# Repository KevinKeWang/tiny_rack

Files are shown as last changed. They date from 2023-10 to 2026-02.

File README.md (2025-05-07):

# tiny_rack
This is a V2 version of tiny_rack. With the release of the BambuLab H2D it's easy to print larger models. So I updated the eurorack case model for the 6U52HP, and the power board circuit for a more convenient and easy to use design. This version is closer to the aluminum eurorack case I sell. they are exactly the same in power and functionality. Now you can print your own 6U52hp eurorack case in any color you like!

tiny_rack_v2_1
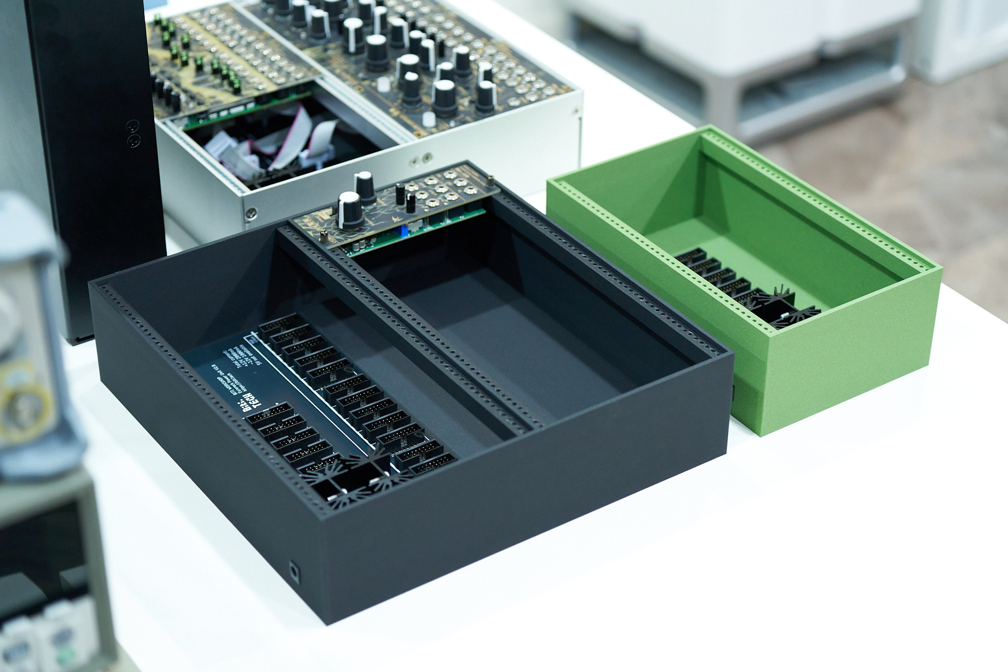
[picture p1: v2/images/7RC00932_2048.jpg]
tiny_rack_v2_2

**(tiny_rack v2)**

The first version is smaller and fits most 3D printers. If your printer cannot build such a large part, please browse the V1 version here: https://github.com/KevinKeWang/tiny_rack/tree/V1

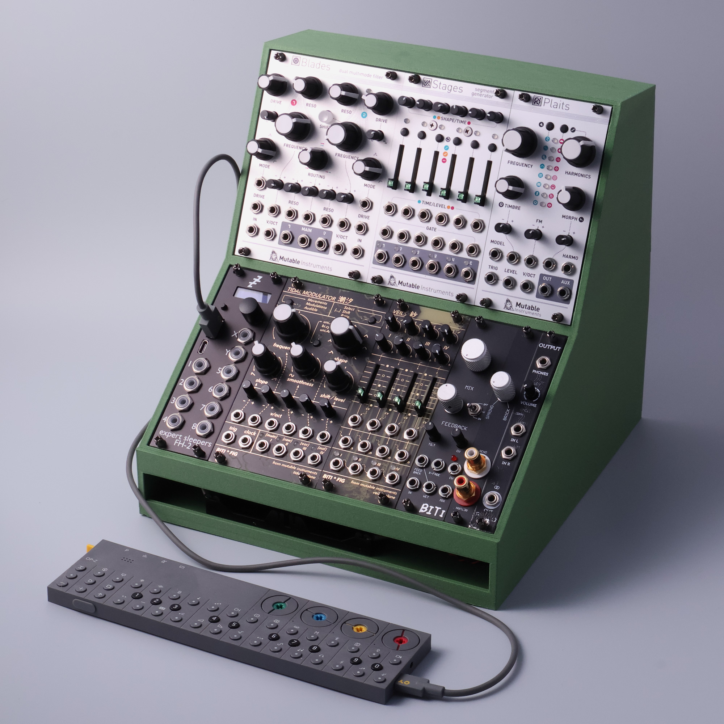
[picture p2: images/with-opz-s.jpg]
tiny_rack

**(tiny_rack v1)**

## Main features:

* One-piece 3D printed, no splicing, no metal rails required.
* Maximum current: +12V 2000mA, -12V 1000mA, +5V not available.
* Full load tested.
* The +12V and -12V output ripple is less than 100mV under all load conditions.
* Fully test powered by ZITAY D-Tap to DC(5.5 * 2.1 mm) Cable

## Portable scene using V-mount battery power supply
**Please note that the dtap output voltage should not be lower than 14.2V**
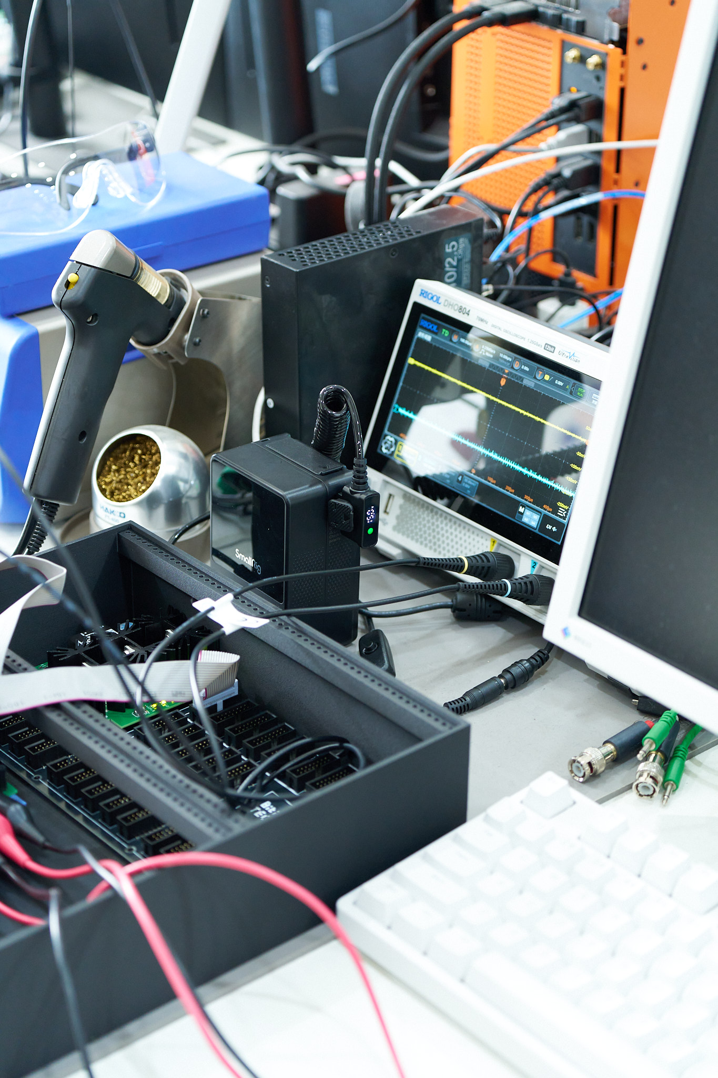
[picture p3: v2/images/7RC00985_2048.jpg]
portable_1
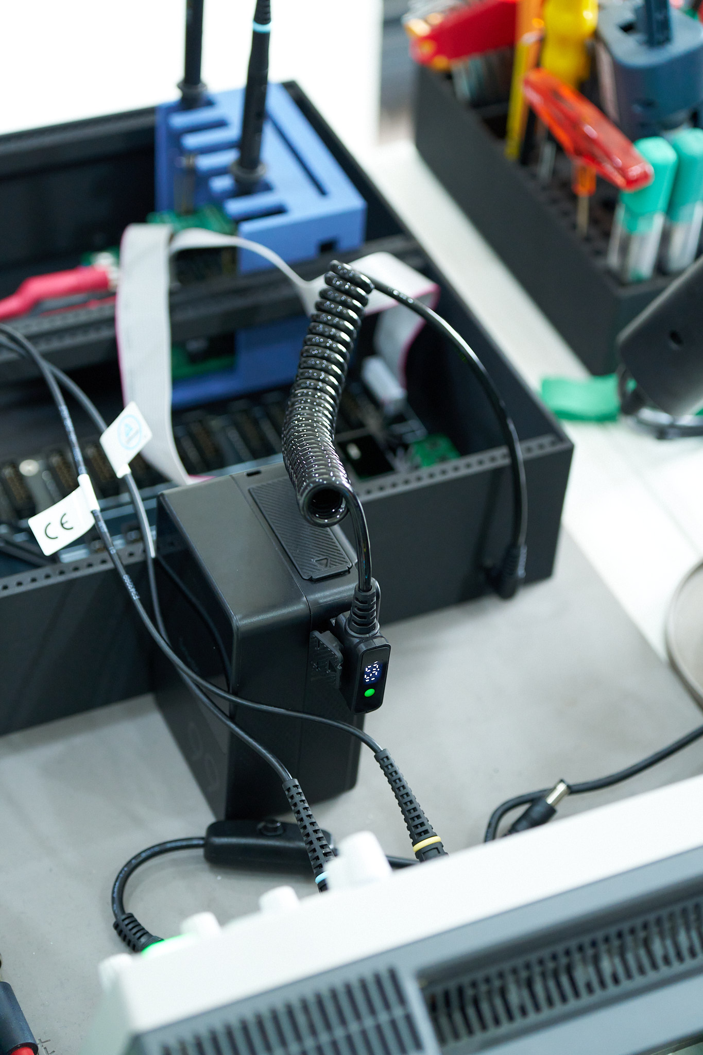
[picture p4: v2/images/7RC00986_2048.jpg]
portable_2
|  |  |
|---|---|

## Instructions
The main reason I started this project was the difficulty in finding a simple power bank solution when I was just starting out with DIY modulars. Most of the solutions required specialized rails. needed to control the precision otherwise the modulars would be difficult to install. there were many power board solutions but I couldn't be sure about the quality of their output. Some switching power supplies cause digital modulars to fail to boot.

This series contains the complete series of racks. and a power board with a decent quality of output. The racks is built entirely using 3D printing. one piece (including the rails) and simple to print. the screw holes are not threaded and need to be force screwed in using M3 screws to create the threads. this sacrifices the strength of the racks somewhat. but again makes the build very simple and ready to use straight after printing.

The power supply uses the original 7812/7912 LDO scheme. which is simple and reliable. and I've tested the ripple on the +/-12V rails to under 100mV under all load conditions. You can check the test report. it's not a perfect solution at the moment. but you can see exactly what kind of standards it can achieve.

**I no longer provide 5V in the power supply since most modulars that use 5V can be switched to convert 5V from 12V**

## 3D Print Instructions
* Be sure to place the model vertically, otherwise the dimensions will be off after printing, resulting in the modular not being installed.
* I have provided BambuStudio project files that can be used as a reference for the support structure. gcode files can be used directly for printing.
* Because different brands or different diameters of nozzles may produce different results when printing small circular holes. I made a screw hole diameter test model here. It is recommended to use this model to test before printing the modular case, and select the appropriate screw hole diameter to modify the plasticity source file. When I use the BambuLab H2D printer with a 0.4mm nozzle, a 2.5mm screw hole is the best size. If you use the same printer as me, you can directly use my gcode file for printing.

## Schematics and PCB

**Core PCB front side**

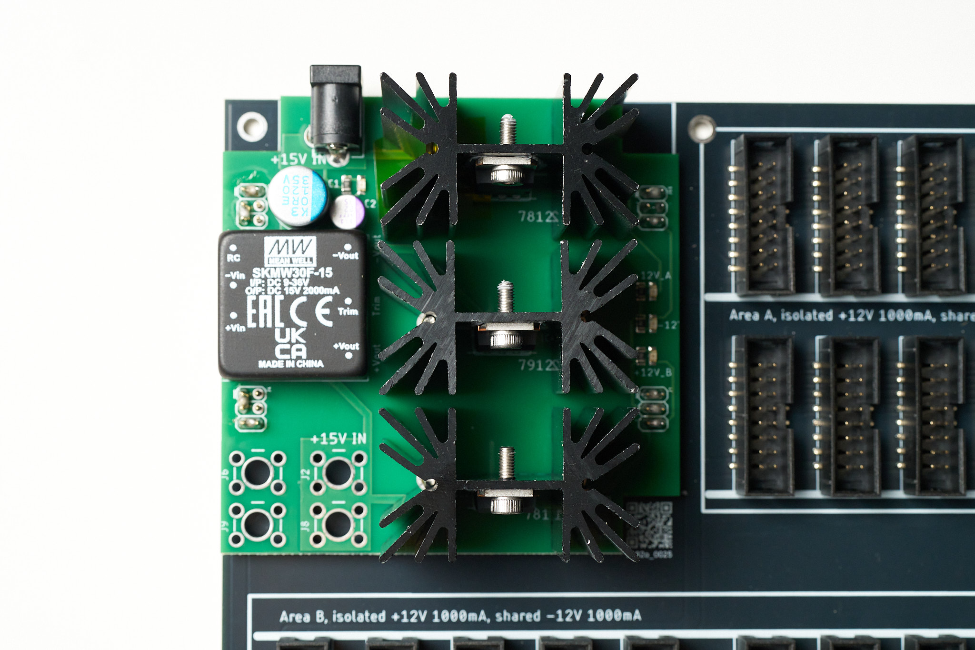
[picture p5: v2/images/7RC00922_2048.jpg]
pcb-front-side


**Core PCB back side**

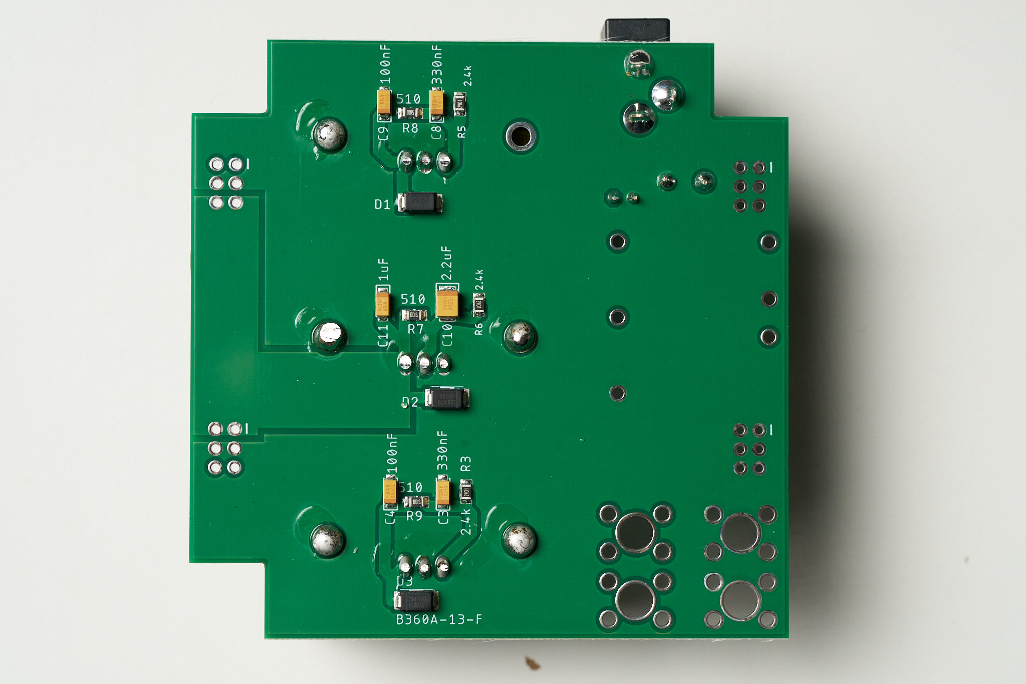
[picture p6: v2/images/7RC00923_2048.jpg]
pcb-back-side


**How to connect two PCBs**

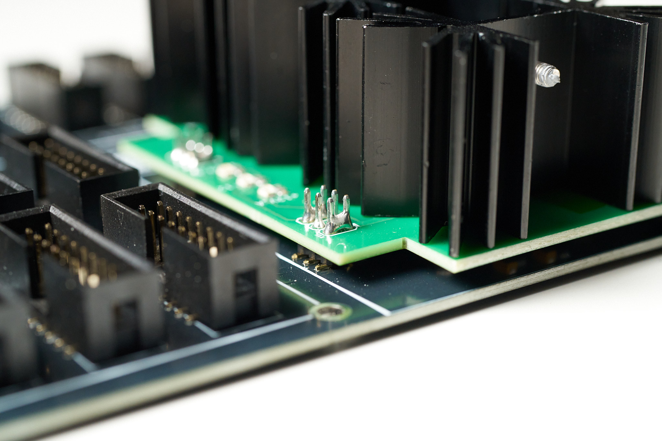
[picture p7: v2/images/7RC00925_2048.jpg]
pcb-connect


## Bill of materials (Core PCB)
| Designator | Qty | Value | Footprint | Description | Ref. Mouser | Ref. LCSC | References |
|---|-----|---|---|---|---|---|---|
| **SMT parts** | | | | | | | |
| LED1, LED2, LED3, LED4 | 4 | LED | 0805 | LED | 638-1215UYCS530A28 | C2987021  | EVERLIGHT 17-215/GHC-YP1Q2B16Y/3T |
| R1, R2, R3, R5, R6, R10, R4  | 7 | 2.4k | 0805 | Resistor | 667-ERJ-6ENF2401V | C17526 | UNI-ROYAL 0805W8F2401T5E |
| R7, R8, R9 | 3 | 510R | 0805 | Resistor (Optional) | 667-ERJ-6ENF5100V | C17734 | UNI-ROYAL 0805W8F5100T5E |
| C4, C9 | 2 | 100nF | CASE-A-3216 | tantalum | 581-TAJA104K035 | C7173 | Kyocera AVX TAJA104K035RNJ |
| C3, C8 | 2 | 330nF | CASE-A-3216 | tantalum | 581-TAJA334K035 | C8014 | Kyocera AVX TAJA334K035RNJ |
| C11 | 1 | 1uF | CASE-A-3216 | tantalum | 581-TAJA105K035R | C7176 | Kyocera AVX TAJA105K035RNJ |
| C10 | 1 | 2.2uF | CASE-B-3528 | tantalum | 581-TAJB225K035 | C19276 | Kyocera AVX TAJB225K035RNJ |
| D1, D2, D3 | 3 | DIODE | SMA(DO-214AC) | DIODE | 621-B360A-F | C94193 | DIODES B360A-13-F |
| **PTH parts** | | | | | | | |
| C2 | 1 | 22uF | D6.3xL7mm | Electrolytic | 647-UKL1V220KEDANA | C433313 | Nichicon USV1V220MFD |
| C1 | 1 | 120uF | D8xL7mm | Electrolytic | 667-50SEK120M | C3010233  | PANASONIC 50SEK120M |
| KK1, KK3, KK4 | 3 | Heat sink | | Heat sink | 532-529702B25G | C286227 | Heat sink |
| J1 | 1 | DC Power Connector | | 2.1 mm, 5.5 mm | 710-694106301002 | C136744 | Wurth Elektronik 694106301002 |
| J2, J6 | 2 | M3 screw terminal  | | terminal (Optional) | 534-7770 | C481448 | Keystone 7770 |
| **Adapter** | | | | | | | |
| 15V Adapter | 1 | 15V Adapter | | GST60A15-P1J | 709-GST60A15-P1J | - | MEANWELL 15V DC Adapter |

**It is recommended to use the adapter model I have tested.**

## Bill of materials (EXP PCB)
| Designator | Qty | Value | Footprint | Description | Ref. Mouser | Ref. LCSC | References |
|---|-----|---|---|---|---|---|---|
| **SMT parts** | | | | | | | |
| J1, J2, J6, J7, J8, J9, J11, J12, J13, J14, J15, J16, J17, J18, J19, J20, J21, J22, J23, J24, J25, J26, J27, J28, J29, J30, J31, J32, J33, J34 | 30 | 2x8 header | 2.54mm pitch  | 2x8 header | 710-61231620621 | C2685064 | 2x8 male header, 2.54mm pitch |
| J3, J4, J5, J10 | 4 | 2x3 header | 2.54mm pitch  | 2x3 header | 710-61300621121 | C358692 | 2x3 male header, 2.54mm pitch |

## Mechanical assembly

**There is no circuit on the back of the expansion board, so it can be directly attached to any surface with tape.**

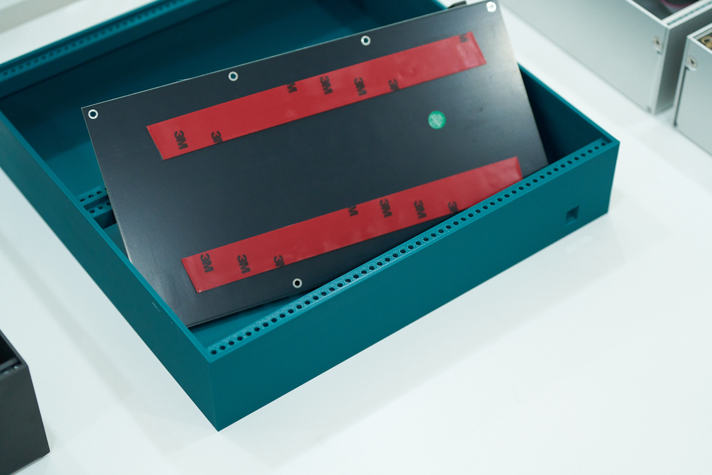
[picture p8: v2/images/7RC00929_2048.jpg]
mount_pic_1


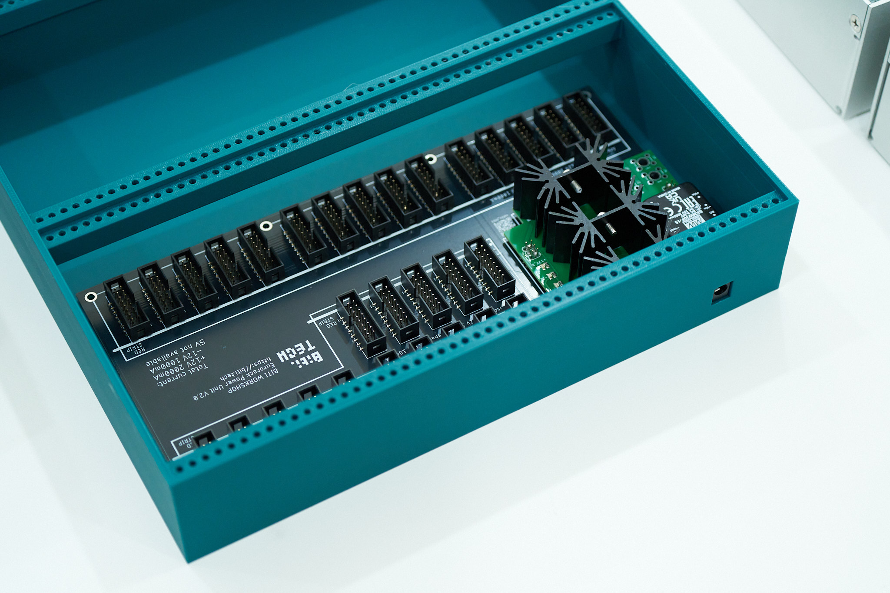
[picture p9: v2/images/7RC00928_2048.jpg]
mount_pic_2


## Software

3D Modeling Software: plasticity

https://www.plasticity.xyz/

PCB Software: eagle

https://www.autodesk.com/products/eagle/overview

## Test Report
Test equipment:
* Gwinstek GPP-3323 DC Power Supply (as an electronic load) **for +12V -12V**
* Itech IT8500G+ DC Electronic Load **for +5V**
* Rigol MSO5000 Oscilloscopes **for ripple measurement**
* Software for automated testing
Test methods:
Each channel is cycled from 0mA to maximum load, 50mA in one step, to test all combinations of loads and output a CSV file.

**There are some power supply solutions that can generate large ripple or even fail in specific load scenarios, such as when the gap between positive and negative rail loads is too large. That's why my tests cover all load scenarios.**

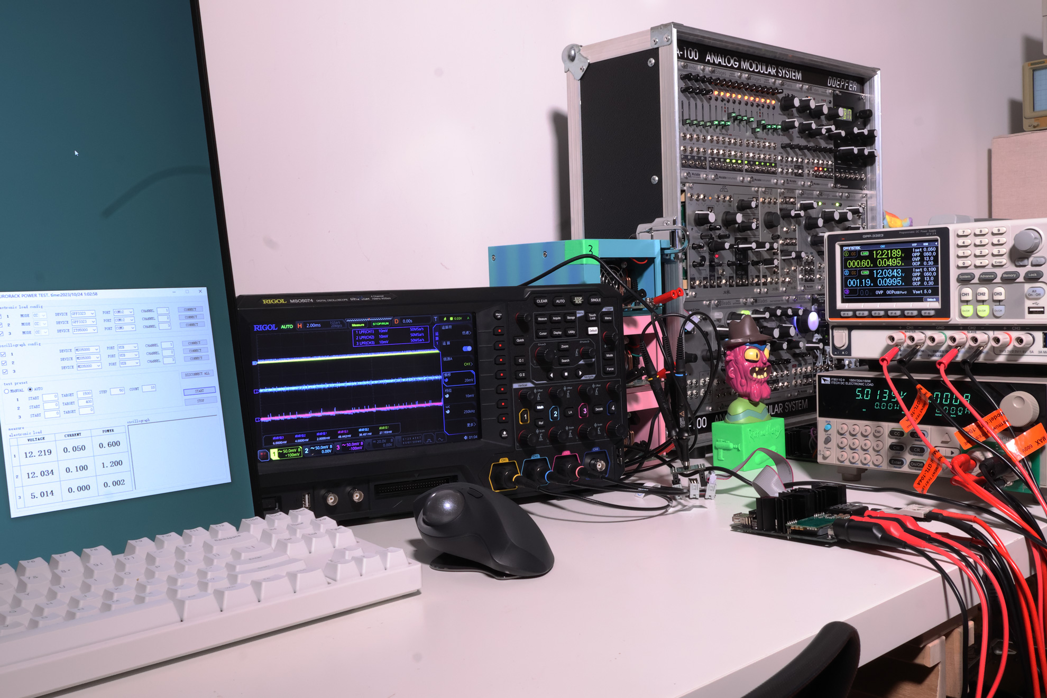
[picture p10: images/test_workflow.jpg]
test_workflow


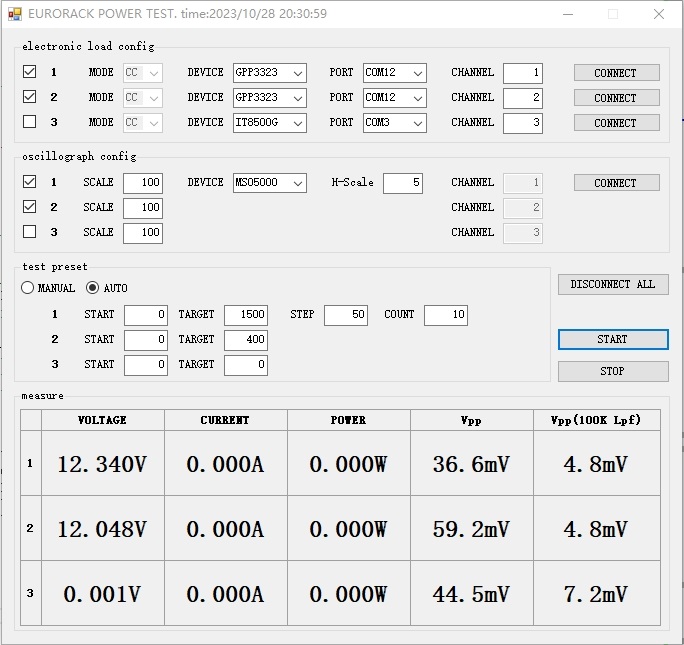
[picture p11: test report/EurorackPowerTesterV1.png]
test_software


## License
**The tiny_rack v2 project is made available under a CC-BY-NC-SA-3.0 license.**

If you want to make a few cases for your own use, go ahead and make them. If you're a synth studio and want to use them for product testing/demonstration etc, that's also welcome as long as it doesn't involve selling these case directly. **Please do not make and sell these case in bulk.**

## Links
Official website:  https://bitiworkshop.com/

Purchase here: https://store.bitiworkshop.com/

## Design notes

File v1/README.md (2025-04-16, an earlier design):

# tiny_rack
tiny_rack is a eurorack case (with power board) project for DIYer who just started DIY eurorack modular synthesizers.

tiny_rack

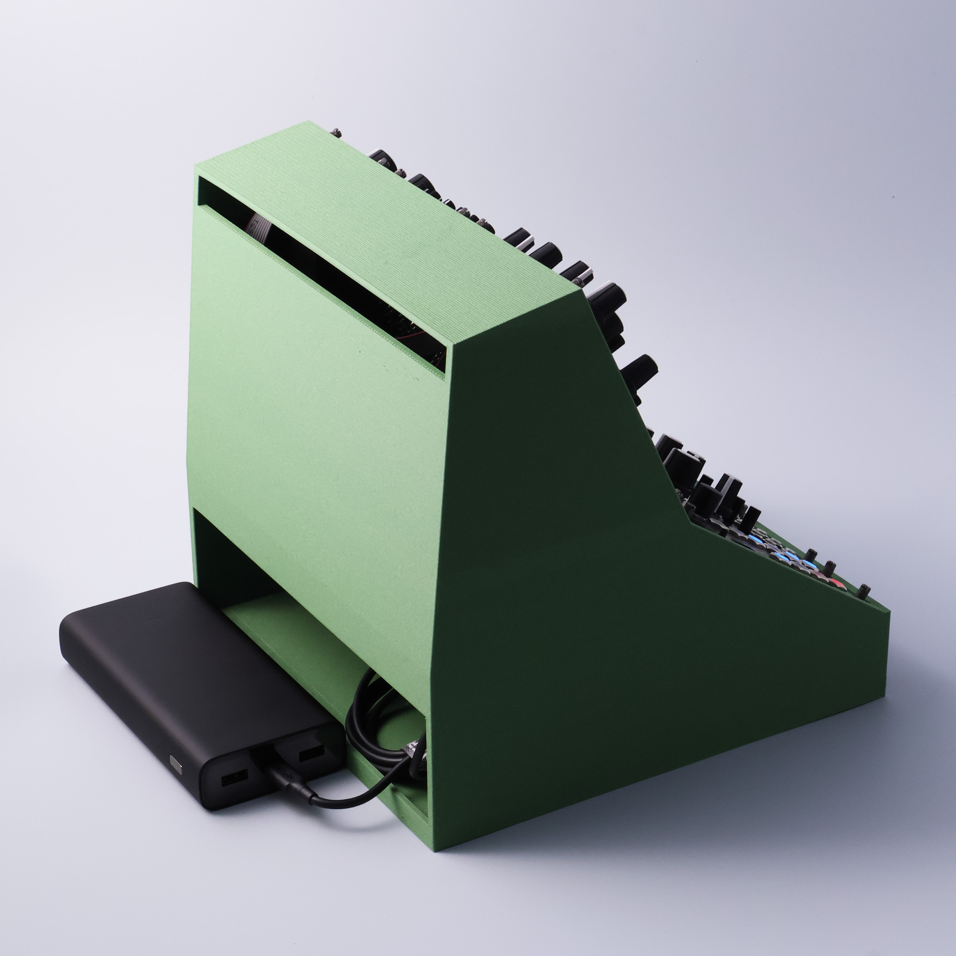
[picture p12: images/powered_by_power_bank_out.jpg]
powered_by_power_bank


## Main features:

* One-piece 3D printed, no splicing, no metal rails required.
* Maximum current: +12V 1500mA, -12V 1500mA, +5V 6500mA.
* Optional +3.3V 500mA for easy project prototyping.
* Full load tested.
* The +12V and -12V output ripple is less than 100mV under all load conditions.
* Exposed M3 screw terminals for direct connection to the test power supply. Clamps can be directly.
* Fully test powered by **[Mi 50w Power Bank 20000mAh](https://www.mi.com/global/product/mi-50w-power-bank-20000/)** (using a 15V USB decoy cable) 

**While this project puts the case and circuit together, they are both independently. This +/-12V 1500mA power supply is usually enough even in a 9U84hp case.**

## Type of rack
| Rack | Min depth | Max depth | Description |
|---|---|---|---|
| tiny-box-18hp | 28mm | 50mm | 18hp |
| tiny-box-26hp | 28mm | 50mm | 26hp |
| tiny-box-34hp | 28mm | 50mm | 34hp |
| tiny-box-42hp | 28mm | 50mm | 42hp |
| tiny-cube-26hp | 78mm | 100mm | 26hp, ultra deep |
| tiny-workbench-34hp | 50mm | 50mm | 34hp, for modular testing |
| tiny-rack-2x44hp | 55mm | 65mm | 2x44hp, more inner space for DIY |

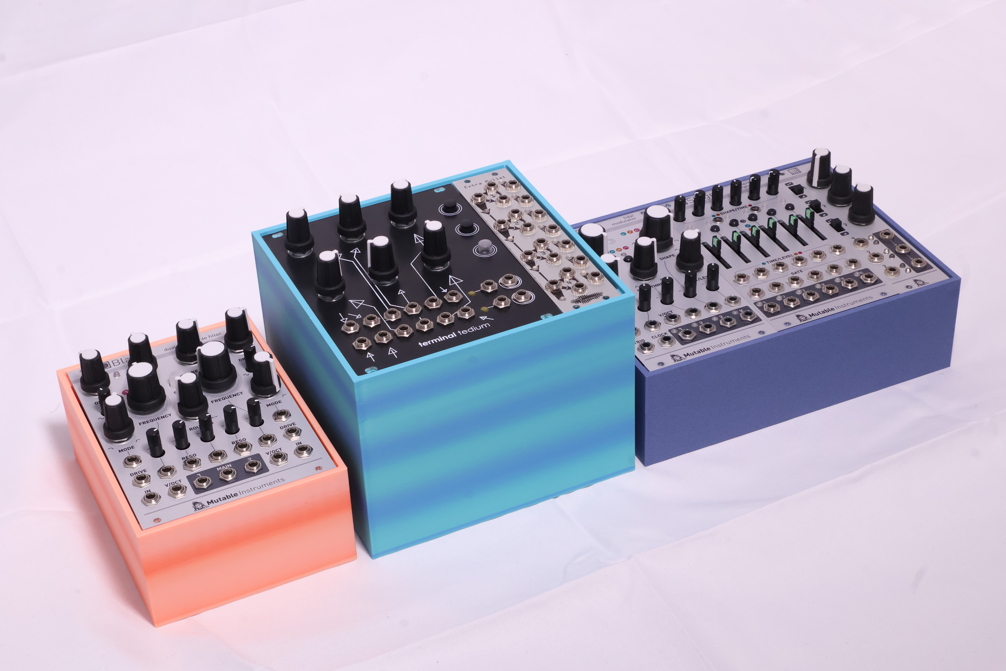
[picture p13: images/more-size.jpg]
more_size


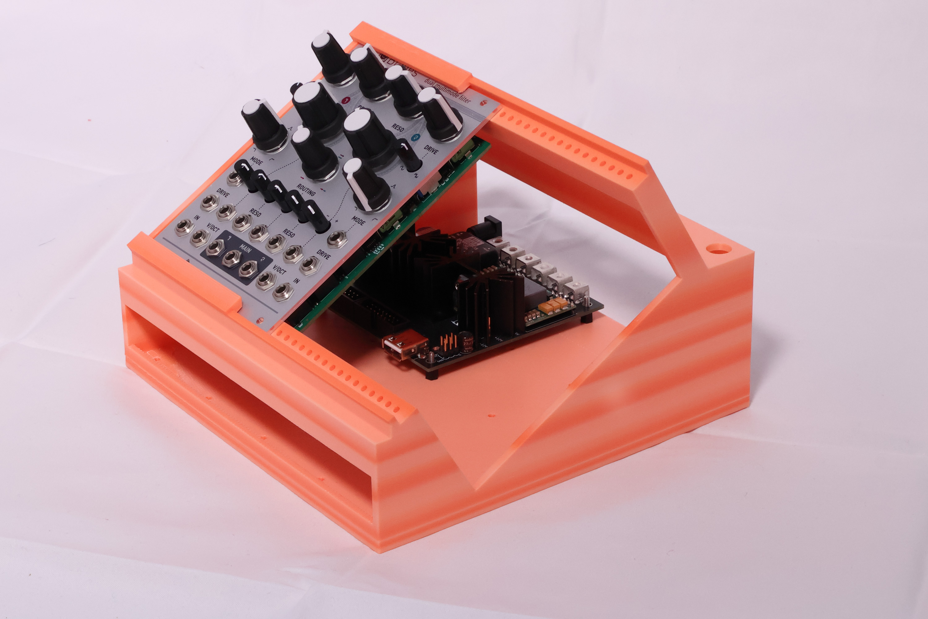
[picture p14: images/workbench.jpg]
workbench


## Instructions
The main reason I started this project was the difficulty in finding a simple power bank solution when I was just starting out with DIY modules. Most of the solutions required specialized rails. needed to control the precision otherwise the modules would be difficult to install. there were many power board solutions but I couldn't be sure about the quality of their output. Some switching power supplies cause digital modulars to fail to boot.

It took me some time to find the balance between ease of production and quality. This series contains the complete series of racks. and a power board with a decent quality of output. The racks is built entirely using 3D printing. one piece (including the rails) and simple to print. the screw holes are not threaded and need to be force screwed in using M3 screws to create the threads. this sacrifices the strength of the racks somewhat. but again makes the build very simple and ready to use straight after printing. All sizes of the racks are covered in 4CM x 4CM screw holes on the bottom and are compatible with all the PCBs in the project. so there is no need to change the power supply board if you need to change case sizes.

For the power supply. I tested several DC-DC isolation regulators and chose the model with the better output. the +12V rail provides 1500mA current output; the -12V rail can provide 1500mA or 400mA depending on the component selection. 5V rail is optional and can provide 3500mA or 6000A power output. which is perfectly adequate for the Raspberry Pi as well. Finally I have designed an optional 3.3V output pin. which is useful for DIY. if you have some project prototypes that need to use 3.3V this will give you some convenience.

The power supply uses the original 7812/7912 LDO scheme. which is simple and reliable. and I've tested the ripple on the +/-12V rails to under 100mV under all load conditions. You can check the test report. it's not a perfect solution at the moment. but you can see exactly what kind of standards it can achieve.
Regarding the heatsink. I designed two options. One is a standard component with soldering and the other is a customized heatsink with a hole spacing of 32mm x 32mm. with customized heat sink the height of power board can be much lower. 

**In the current scheme, the use of +5V is not recommended and will increase the output ripple on all channels.**

## 3D Print Instructions
* Be sure to place the model vertically, otherwise the dimensions will be off after printing, resulting in the modular not being installed.
* Do not add supports in the screw holes, extremely difficult to remove.
* I have provided BambuStudio project files in the "bumbu p1s" / "bumbu x1c" folder that can be used as a reference for the support structure. gcode files can be used directly for printing.
* It is also recommended to use 0.6mm nozzles. 0.4mm nozzles are often clogged.

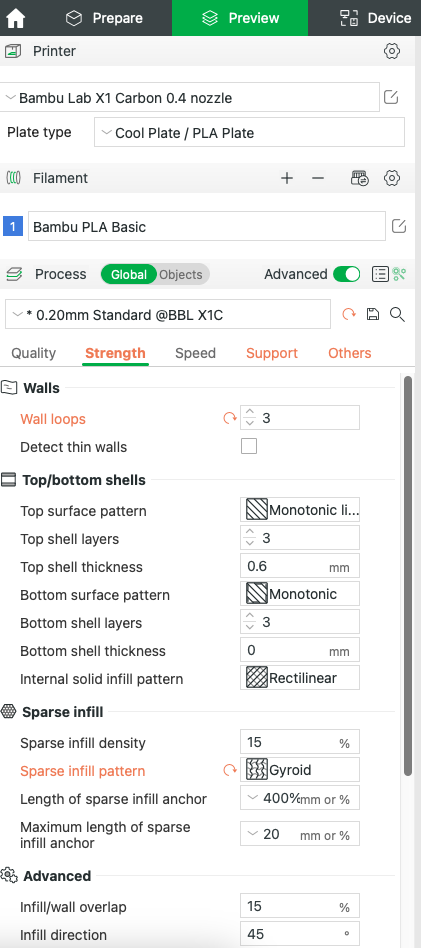
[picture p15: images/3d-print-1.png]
3D Printing Parameters 1

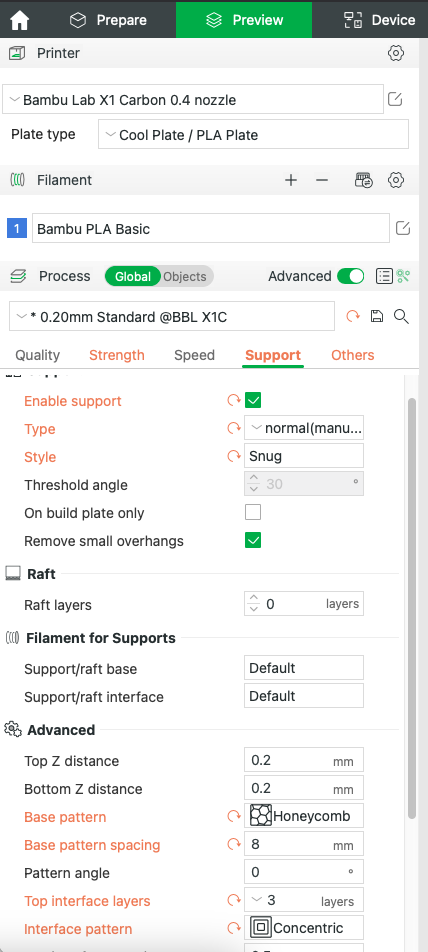
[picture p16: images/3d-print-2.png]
3D Printing Parameters 2

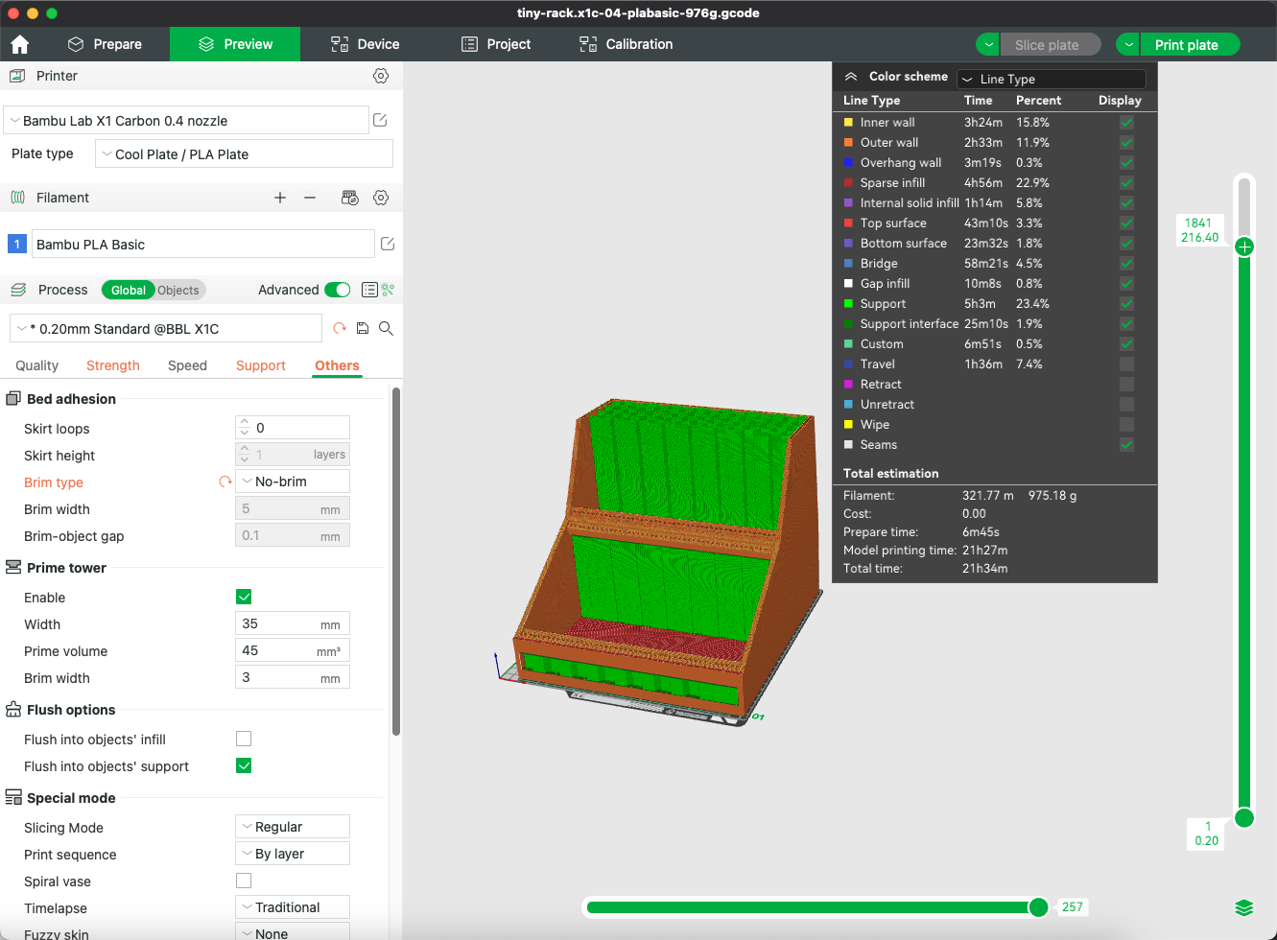
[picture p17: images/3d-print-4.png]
3D Printing Parameters 3


## Schematics and PCB
[All the PCB design files here](https://github.com/KevinKeWang/tiny_rack/tree/93aa4f3181c854528b71964095c1c5eb0407a9e2/power%20pcb "PCB Files")

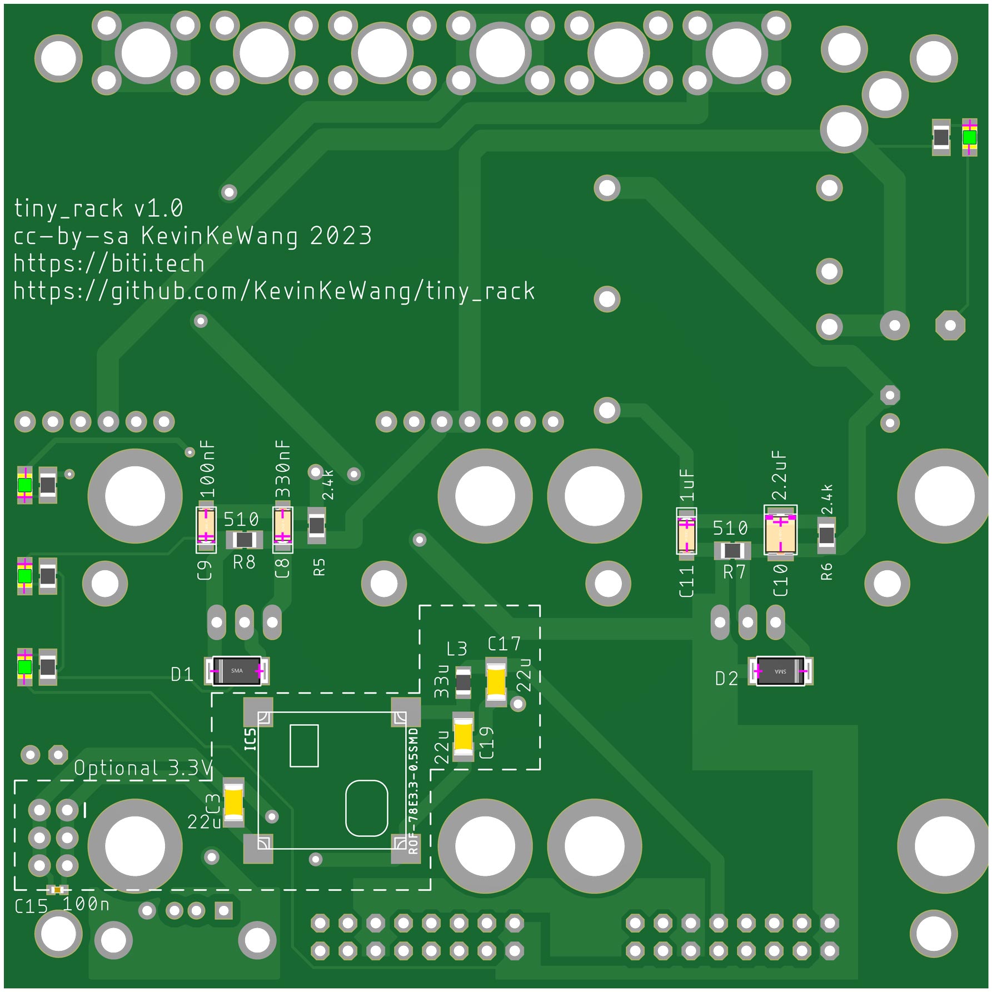
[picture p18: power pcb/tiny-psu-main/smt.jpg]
pcb


## Bill of materials
| Designator | Qty | Value | Footprint | Description | Ref. Mouser | Ref. LCSC | References |
|---|-----|---|---|---|---|---|---|
| **SMT parts** | | | | | | | |
| LED1, LED2, LED3, LED4 | 4 | LED | 0805 | LED | 638-1215UYCS530A28 | C2987021  | EVERLIGHT 17-215/GHC-YP1Q2B16Y/3T |
| R3 | 1 | 1.2k | 0805 | Resistor | 667-ERJ-6ENF1201V | C17379 | UNI-ROYAL 0805W8F1201T5E |
| R1, R2, R4 | 3 | 2.4k | 0805 | Resistor | 667-ERJ-6ENF2401V | C17526 | UNI-ROYAL 0805W8F2401T5E |
| R5, R6 | 2 | 2.4k | 0805 | Resistor (Optional) | 667-ERJ-6ENF2401V | C17526 | UNI-ROYAL 0805W8F2401T5E |
| R7, R8 | 2 | 510R | 0805 | Resistor (Optional) | 667-ERJ-6ENF5100V | C17734 | UNI-ROYAL 0805W8F5100T5E |
| C9 | 1 | 100nF | CASE-A-3216 | tantalum | 581-TAJA104K035 | C7173 | Kyocera AVX TAJA104K035RNJ |
| C8 | 1 | 330nF | CASE-A-3216 | tantalum | 581-TAJA334K035 | C8014 | Kyocera AVX TAJA334K035RNJ |
| C11 | 1 | 1uF | CASE-A-3216 | tantalum | 581-TAJA105K035R | C7176 | Kyocera AVX TAJA105K035RNJ |
| C10 | 1 | 2.2uF | CASE-B-3528 | tantalum | 581-TAJB225K035 | C19276 | Kyocera AVX TAJB225K035RNJ |
| D1, D2 | 2 | DIODE | SMA(DO-214AC) | DIODE | 621-B360A-F | C94193 | DIODES B360A-13-F |
| C15 | 1 | 100nF | 0402 | Ceramic (Optional for 3.3V) | 187-CL05B104KB54PNC | C307331 | SAMSUNG CL05B104KB54PNC |
| C3, C17, C19 | 3 | 22uF | 1206 | Ceramic (Optional for 3.3V) | 187-CL31A226KAHNNNE | C12891 | SAMSUNG CL31A226KAHNNNE |
| L3 | 1 | 33uH | 0805 | Inductor (Optional for 3.3V) | 810-MLZ2012M330WT000 | C383405 | TDK MLZ2012M330WT000 |
| **PTH parts** | | | | | | | |
| C2, C6 | 2 | 22uF | D6.3xL7mm | Electrolytic | 647-UKL1V220KEDANA | C433313 | Nichicon USV1V220MFD |
| C1 | 1 | 120uF | D8xL7mm | Electrolytic | 667-50SEK120M | C3010233  | PANASONIC 50SEK120M |
| IC3 | 1 | 7812 | TO-220 | LDO | 511-L7812CV-DG | C2914 | ST L7812CV-DG |
| IC4 | 1 | 7912 | TO-220 | LDO | 511-L7912CV-DG | C3797 | ST L7912CV-DG |
| IC1 | 1 | dc-dc converter | | dc-dc converter | 709-SKMW06F-15 **or** 709-SKMW30F-15 | | isolated dc-dc regulated converter |
| KK1, KK2, KK3, KK4 | 2 | Heat sink | | Heat sink | 532-529702B25G | C286227 | Heat sink |
| J7 | 1 | DC Power Connector | | 2.1 mm, 5.5 mm | 710-694106301002 | C136744 | Wurth Elektronik 694106301002 |
| IC2 | 1 | dc-dc converter | | Converter (Optional for 5V) | 709-NID65-5 | | MEANWELL NID65-5 (support +5V 6500mA) |
| J5 | 1 | USB Connector | USB2.0 TYPE-A | Connector (Optional for 5V) | 710-614004190021 | C2880666  | Wurth Elektronik 614004190021 |
| IC5 | 1 | 3.3V converter | | Converter (Optional for 3.3V)  | 919-ROF78E3.3-.5SMDR | - | RECOM Power ROF-78E3.3-0.5SMD-R |
| J3 | 1 | 2x3 header | 2.54mm pitch  | 2x3 header (Optional for 3.3V) | 710-61300621121 | C358692 | 2x3 male header, 2.54mm pitch |
| J2, J6, J8, J9, J10, J11 | 6 | M3 screw terminal  | | terminal (Optional) | 534-7770 | C481448 | Keystone 7770 |
| X1, X7 | 2 | 2x8 header | 2.54mm pitch  | 2x8 header | 710-61201621621 | C429960 | 2x8 male header, 2.54mm pitch |
| **Hardware Mount** | | | | | | | |
| flathead screw | 4 | M2.5 x 20mm | | | | | for pcb mount |
| hex nylon nuts | 4 | M2.5 x 8mm | | | | | for pcb mount |
| mounting screws | 4 | M3 x 10mm + 6mm | |  (Optional for heat sink) | | | for heat sink mount |
| spring | 4 | 7mm x 5mm | |  (Optional for heat sink) | | | for heat sink mount |
| **Adapter** | | | | | | | |
| 15V Adapter | 1 | 15V Adapter | | GST60A15-P1J | 709-GSM36B15-P1J **or** 709-GST60A15-P1J | - | MEANWELL 15V DC Adapter |

IC1: isolated dc-dc regulated converter (choose one) :  MEANWELL SKMW06F-15 (support -12V 400mA) or MEANWELL SKMW30F-15 (support -12V 1500mA)

Heat sink (choose one): 40x40x6mm Customized heat sink with 32x32mm hole spacing or 42x25x25mm Standard heat sinks

15V DC Adapter (choose one): MEANWELL GSM36B15-P1J (15V 36W) for 12V 400mA or MEANWELL GST60A15-P1J (15V 60W) for -12V 1500mA

**It is recommended to use the adapter model I have tested.**

## Mechanical assembly

**use regular heat sink:**

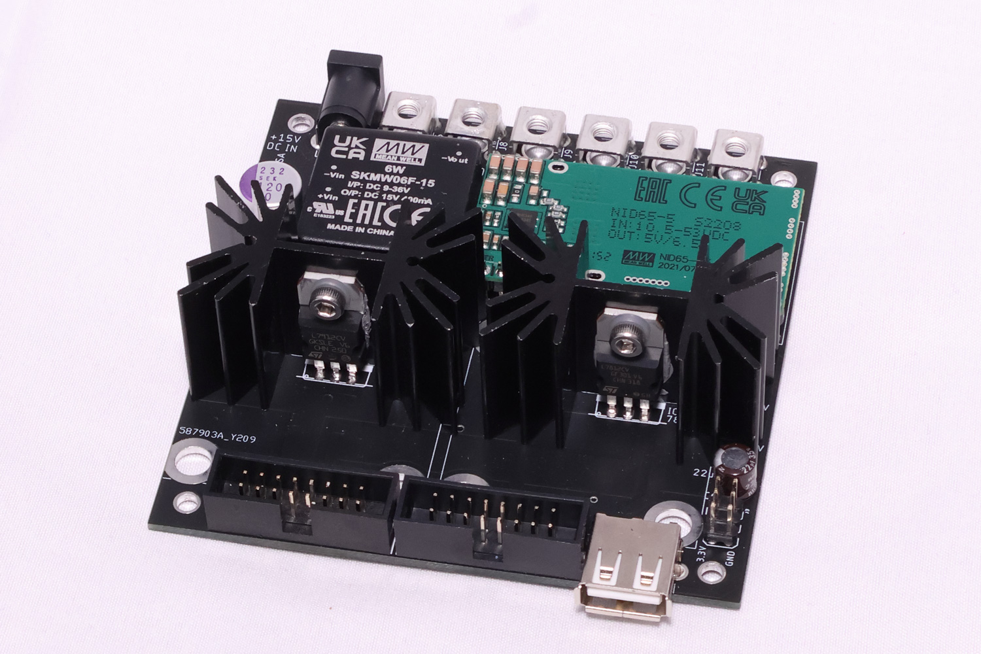
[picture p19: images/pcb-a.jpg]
use_regulated_heat_sink


**use customized heat sinks:**

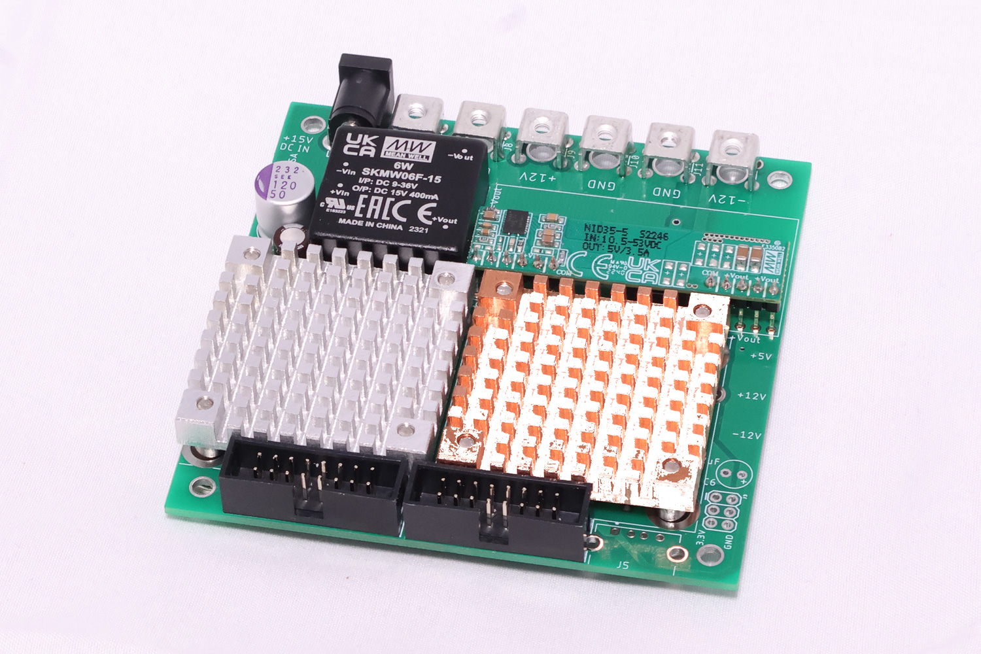
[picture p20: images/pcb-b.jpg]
use_custom_heat_sink


**mounting guide:**

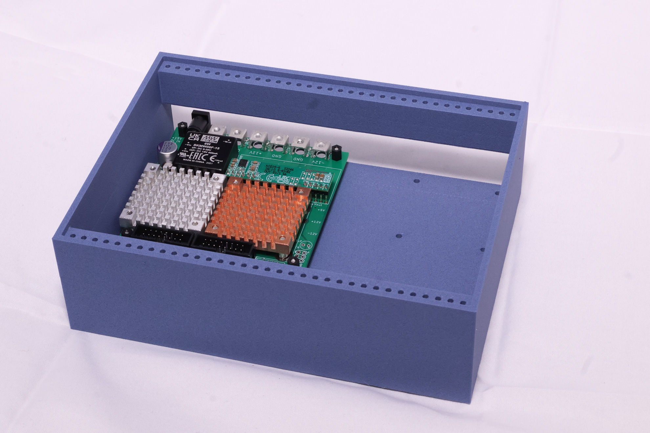
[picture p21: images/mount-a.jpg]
mount_pic_1


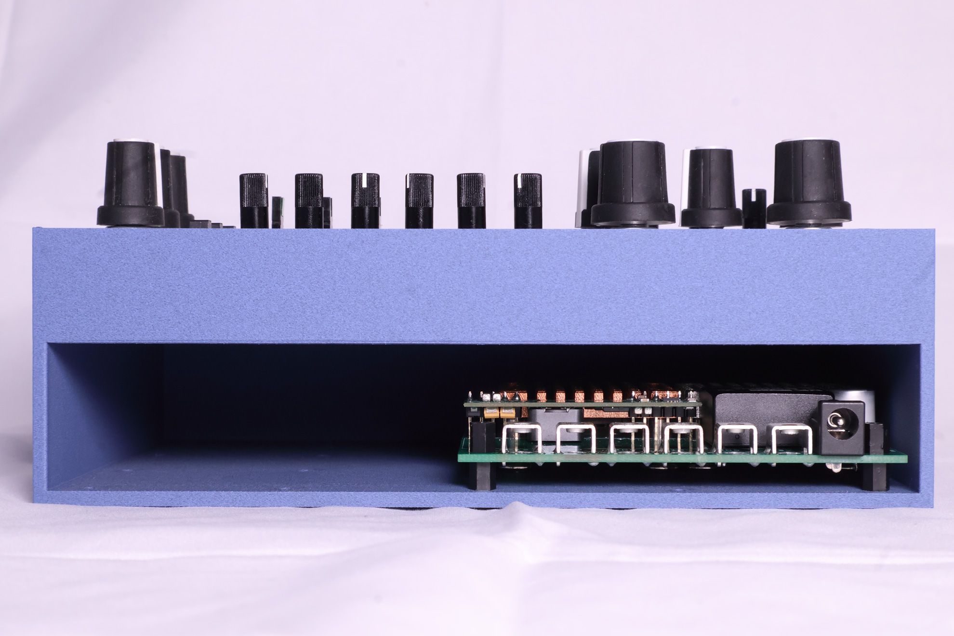
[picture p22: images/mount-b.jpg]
mount_pic_2


**short circuit protection:**

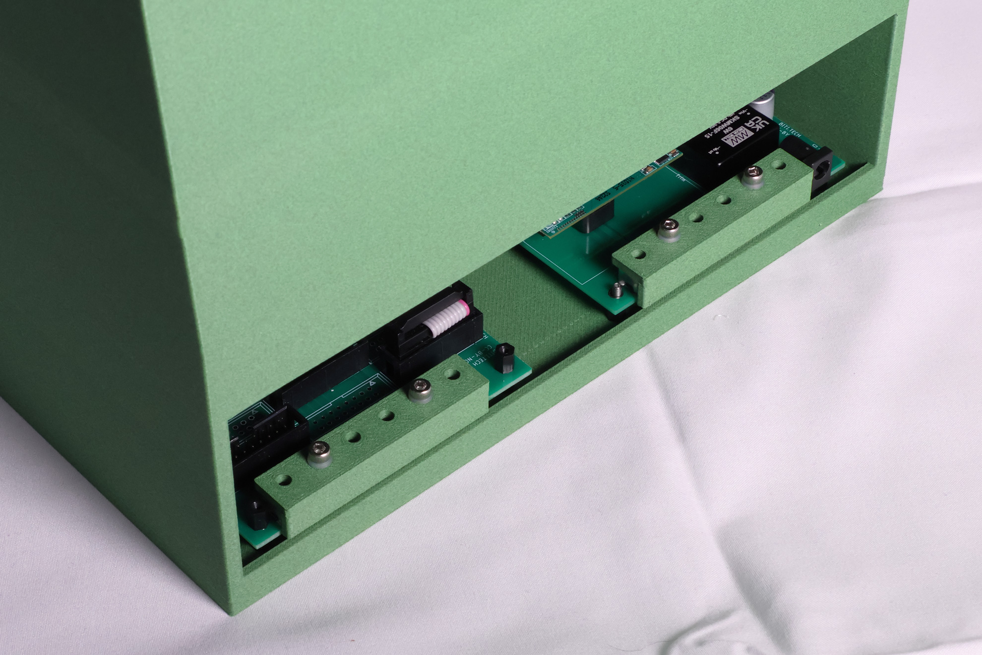
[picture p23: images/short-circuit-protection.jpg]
mount_pic_3


## Test Report
Test equipment:
* Gwinstek GPP-3323 DC Power Supply (as an electronic load) **for +12V -12V**
* Itech IT8500G+ DC Electronic Load **for +5V**
* Rigol MSO5000 Oscilloscopes **for ripple measurement**
* Software for automated testing
Test methods:
Each channel is cycled from 0mA to maximum load, 50mA in one step, to test all combinations of loads and output a CSV file.

**There are some power supply solutions that can generate large ripple or even fail in specific load scenarios, such as when the gap between positive and negative rail loads is too large. That's why my tests cover all load scenarios.**

test_workflow

test_software

Test result (use SKMW06F-15 and GSM36B15-P1J) [full test file](https://github.com/KevinKeWang/tiny_rack/blob/194db1126690bd216e786f4cb923c7edc125c2ce/test%20report/TestReport_SKMW06F-15_and_GSM36B15-P1J.csv):

| Output | Maximum load | Maximum ripple |
|---|---|---|
| +12V | 1500mA | 60mV |
| -12V | 400mA | 50mV |
| +5V | - | untested |
| +3.3V | - | untested |

Test result (use SKMW06F-15 and **Mi 50w Power Bank 20000mAh**) [full test file](https://github.com/KevinKeWang/tiny_rack/blob/194db1126690bd216e786f4cb923c7edc125c2ce/test%20report/TestReport_SKMW06F-15_and_Mi_50w_Power_Bank_20000mAh.csv):

| Output | Maximum load | Maximum ripple |
|---|---|---|
| +12V | 1500mA | 80mV |
| -12V | 400mA | 50mV |
| +5V | - | untested |
| +3.3V | - | untested |

Test result (use SKMW30F-15 and GST60A15-P1J) [full test file](https://github.com/KevinKeWang/tiny_rack/blob/194db1126690bd216e786f4cb923c7edc125c2ce/test%20report/TestReport_SKMW30F-15_and_GST60A15-P1J.csv):

| Output | Maximum load | Maximum ripple |
|---|---|---|
| +12V | 1500mA | 183mV |
| -12V | 1500mA | 163mV |
| +5V | 6500mA | untested |
| +3.3V | 500mA | untested |

## License
This 3D model and PCB layout is made available under a cc-by-sa-3.0 license.

## Links
Official website:  https://bitiworkshop.com/

Thingiverse: https://www.thingiverse.com/thing:6279851

Purchase here: https://store.bitiworkshop.com/

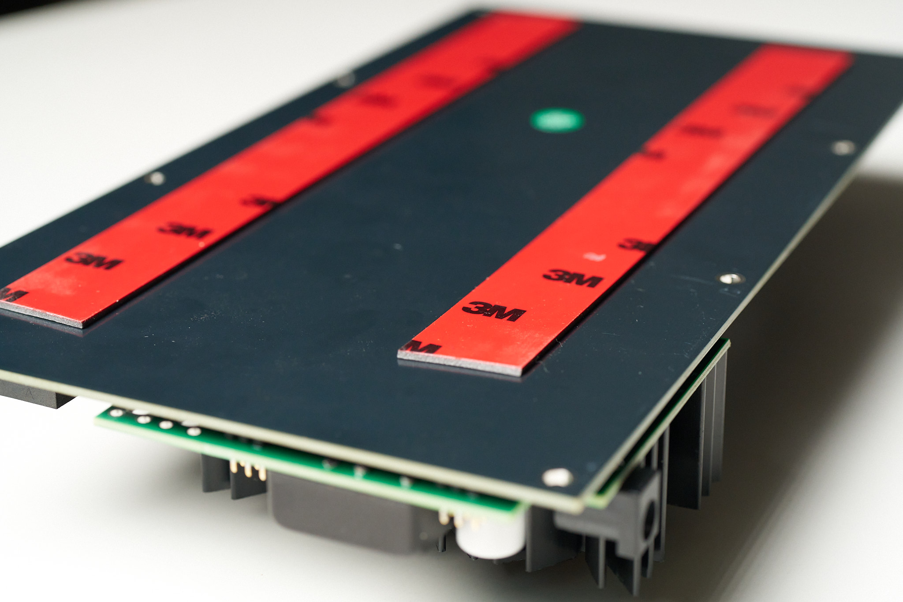
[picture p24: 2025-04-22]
v2/images/7RC00926_2048.jpg

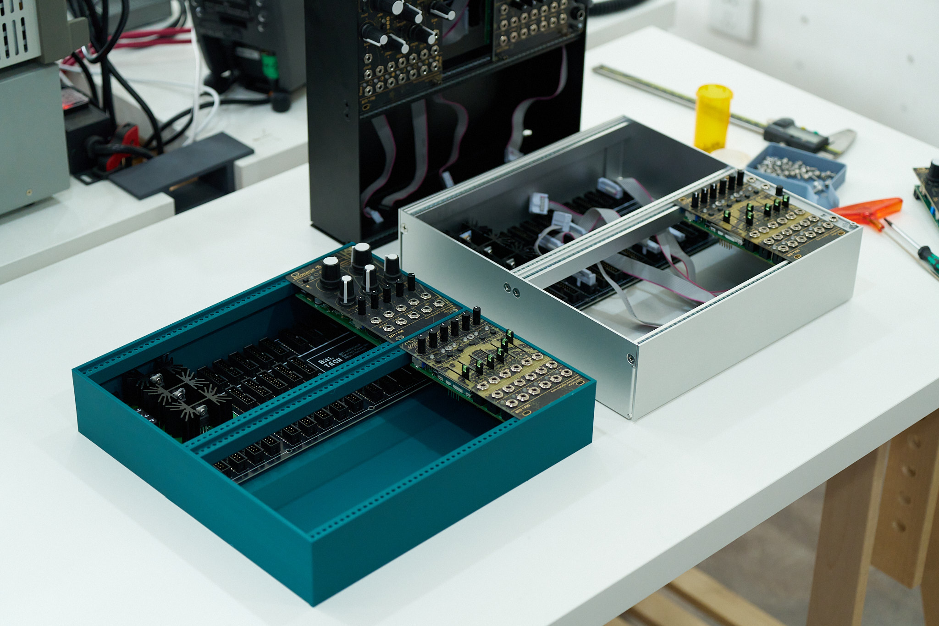
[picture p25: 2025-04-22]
v2/images/7RC00930_2048.jpg

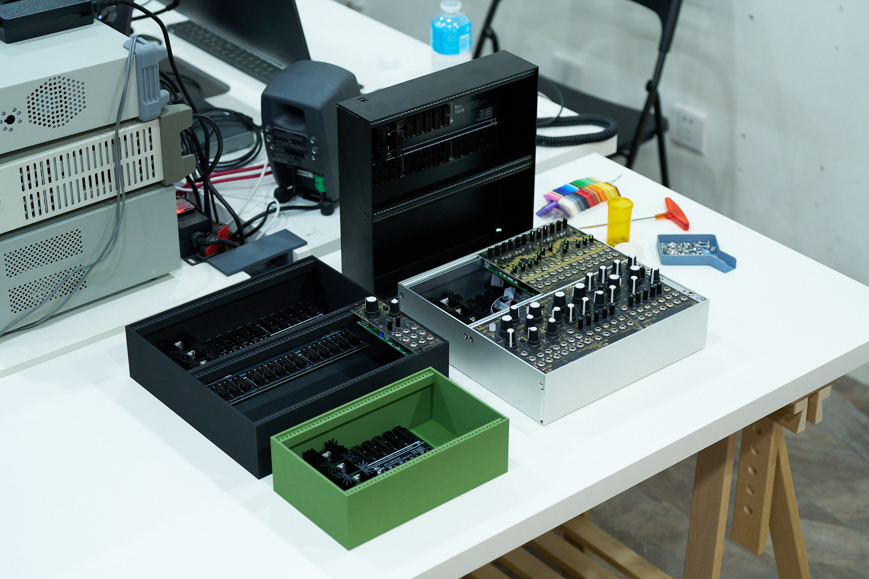
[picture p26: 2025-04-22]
v2/images/7RC00934_2048.jpg

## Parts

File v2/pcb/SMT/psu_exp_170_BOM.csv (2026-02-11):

Designator | Comment | Footprint | 嘉立创元件编号
J10,J3,J4,J5 | 2X3PIN | SMT | C780054
J1,J11,J12,J13,J14,J2,J6,J7,J8,J9 | 2X8PIN | SMT | C2685064

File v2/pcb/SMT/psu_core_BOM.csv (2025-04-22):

Designator | Qty | Comment | Footprint | JLC PartNo.
LED1, LED2, LED3, LED4 | 4 | LED | 0805 | C389524
C4, C9 | 2 | 100nF | C7173 | C7173
C1 | 1 | 120uF | C134861 | C134861
C11 | 1 | 1uF | C7176 | C7176
C10 | 1 | 2.2uF | C19276 | C19276
R1, R2, R3, R5, R6, R10, R4 | 7 | 2.4k | 0805 | C17526
C2 | 1 | 22uF | C1578600 | C1578600
J2, J6, J8, J9 | 4 | 30A-SCREW-CONN | 50X72 | C481448
C3, C8 | 2 | 330nF | C8014 | C8014
R7, R8, R9 | 3 | 510R | 0805 | C17734
D1, D2, D3 | 3 | B360A-13-F | DO-214AC | C94193
KK1, KK3, KK4 | 3 | C286227 | C286227 | C286227
J1 | 1 | C136744 | C136744 | C136744

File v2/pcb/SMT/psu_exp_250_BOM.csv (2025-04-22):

Designator | Comment | Footprint | JLC PartNo.
J3, J4, J5, J10 | 2X3PIN | SMT | C780054
J1, J2, J6, J7, J8, J9, J11, J12, J13, J14, J15, J16, J17, J18, J19, J20, J21, J22, J23, J24, J25, J26, J27, J28, J29, J30, J31, J32, J33, J34 | 2X8PIN | SMT | C2685064

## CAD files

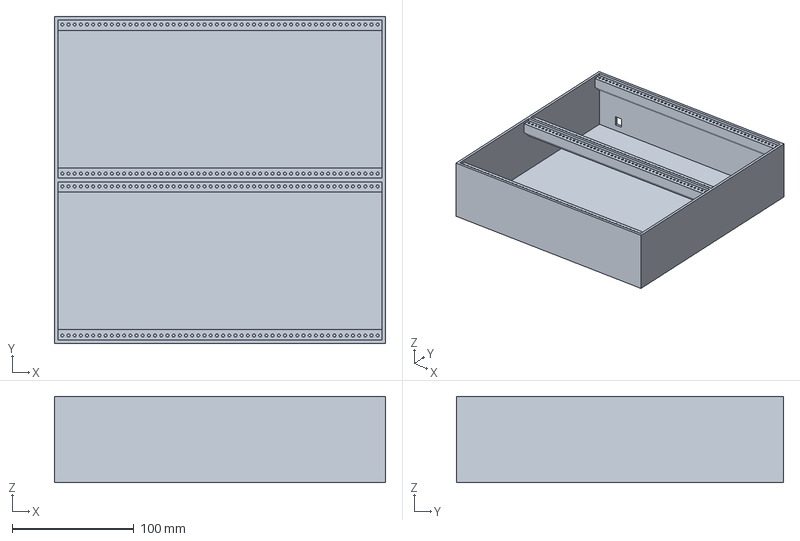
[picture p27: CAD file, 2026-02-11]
v2/3d print case/bambulab studio project file/6U52hp.3mf
271.9 x 269.0 x 71.0 mm

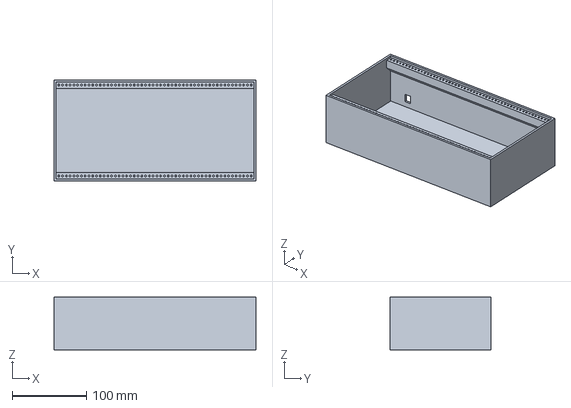
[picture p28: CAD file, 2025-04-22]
v2/3d print case/stp/3U52hp-71mm-2.5hole.stp
271.9 x 136.0 x 71.0 mm

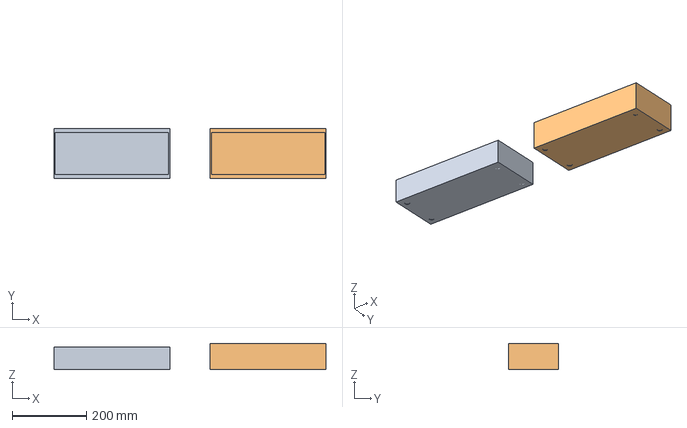
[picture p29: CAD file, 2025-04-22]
v2/3d print case/bambulab studio project file/3U60hp.3mf
734.3 x 136.2 x 71.0 mm
3U60hp-61mm-2.5hole.stp
3U60hp-71mm-2.5hole.stp

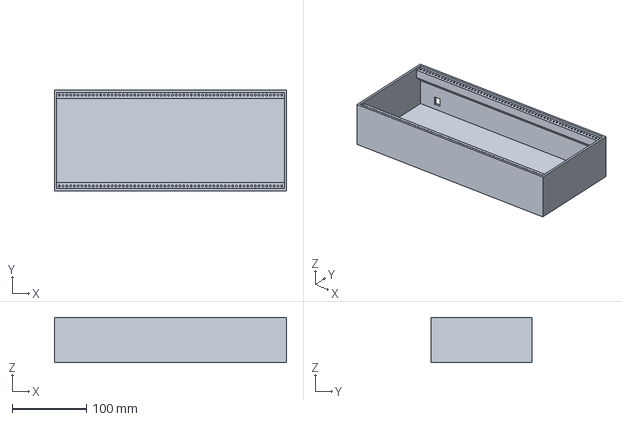
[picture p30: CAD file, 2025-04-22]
v2/3d print case/stp/3U60hp-61mm-2.7hole.stp
312.5 x 136.0 x 61.0 mm

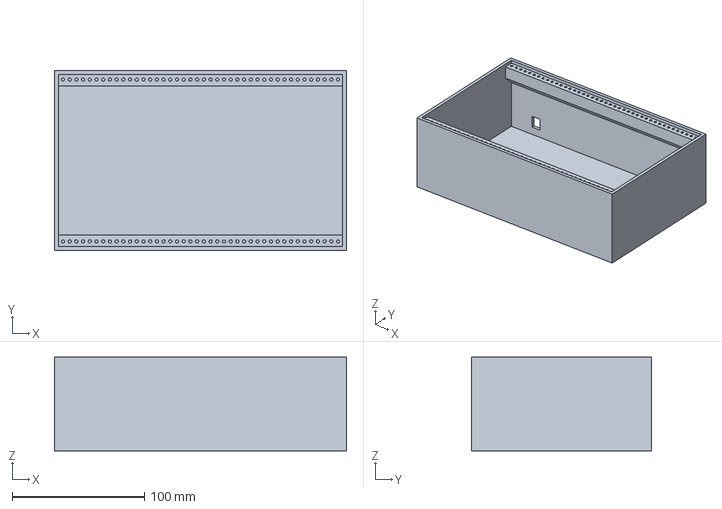
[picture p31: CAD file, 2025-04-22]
v2/3d print case/bambulab studio project file/3U42hp.3mf
221.1 x 136.0 x 71.0 mm

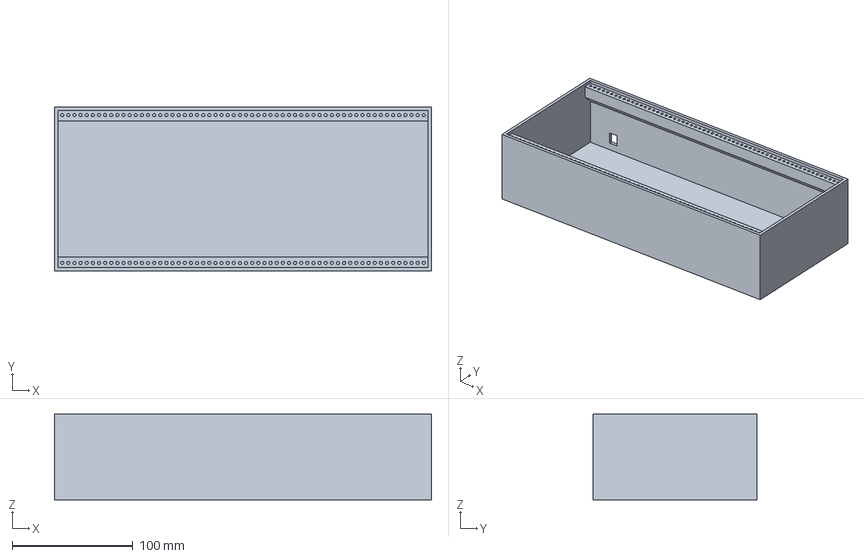
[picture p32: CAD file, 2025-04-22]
v2/3d print case/stp/3U60hp-71mm-2.7hole.stp
312.5 x 136.0 x 71.0 mm

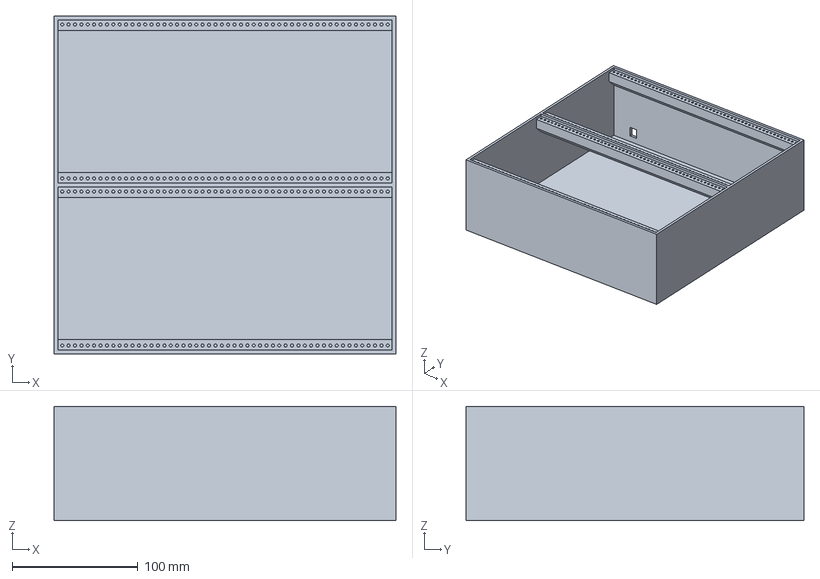
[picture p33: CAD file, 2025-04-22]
v2/3d print case/stp/6U52hp-91mm-2.5hole.stp
271.9 x 269.0 x 91.0 mm

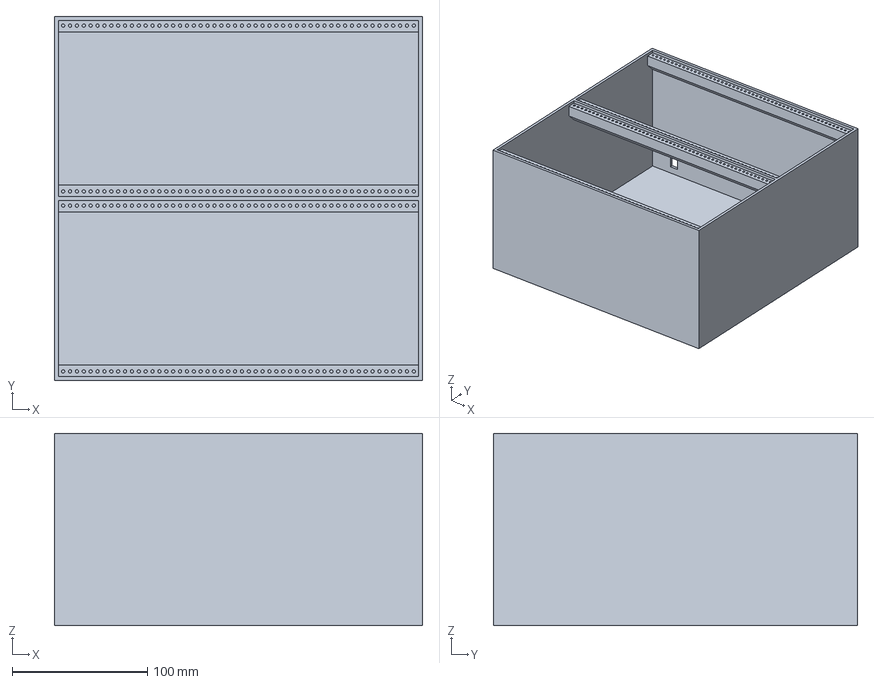
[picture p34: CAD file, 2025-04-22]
v2/3d print case/stp/6U52hp-142mm-2.5hole.stp
271.9 x 269.0 x 142.0 mm

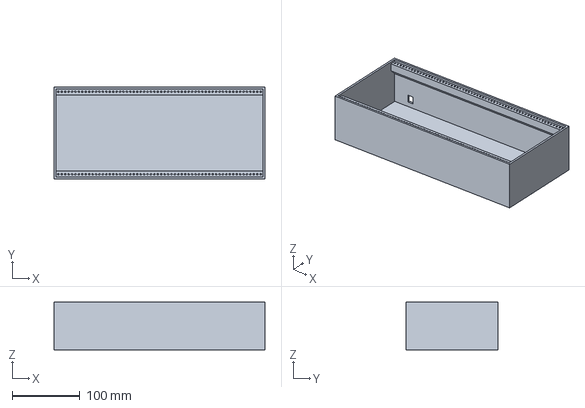
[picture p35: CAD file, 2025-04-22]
v2/3d print case/stp/3U60hp-71mm-2.5hole.stp
312.5 x 136.0 x 71.0 mm

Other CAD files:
v2/3d print case/bambulab studio project file/3U52hp.3mf
v2/3d print case/stp/3U42hp-71mm-2.5hole.stp
v2/3d print case/stp/3U60hp-61mm-2.5hole.stp
v2/3d print case/stp/6U52hp-71mm-2.5hole.stp
v2/3d print case/stp/6U52hp-71mm-2.7hole.stp
v2/3d print case/stp/3U52hp-71mm-2.7hole.stp
v2/3d print case/stp/6U52hp-142mm-2.7hole.stp
v2/3d print case/stp/6U52hp.stp
v2/3d print case/stp/6U52hp-91mm-2.7hole.stp
v1/3d print case/adapter/connector-cap.stl
v1/3d print case/adapter/connector-cap.stp
v1/3d print case/adapter/transformer-adapter.stl
v1/3d print case/adapter/transformer-adapter.stp
v1/3d print case/tiny rack (box)/bumbu p1s/bumbu p1s gcode/tiny-box-18hp.p1s-06-plabasic-135g.gcode.3mf
v1/3d print case/tiny rack (box)/bumbu p1s/bumbu p1s gcode/tiny-box-18hp.p1s-06-placf-131g.gcode.3mf
v1/3d print case/tiny rack (box)/bumbu p1s/bumbu p1s gcode/tiny-box-26hp.p1s-06-plabasic-170g.gcode.3mf
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

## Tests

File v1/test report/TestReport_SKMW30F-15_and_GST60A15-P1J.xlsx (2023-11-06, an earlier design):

TestReport_SKMW30F-15_and_GST60A15-P1J
time | voltage1 | current1 | power1 | vpp1 | vpp(lpf100k)1 | voltage2 | current2 | power2 | vpp2 | vpp(lpf100k)2
09:01:28 | 11.762 | 0 | 0 | 55 | 18.4 | 12.501 | 0 | 0 | 77.4 | 8.8
09:01:31 | 11.762 | 0 | 0 | 59.5 | 18.4 | 12.501 | 0 | 0 | 77.4 | 7.2
09:01:36 | 11.761 | 0 | 0 | 59.5 | 17.6 | 12.501 | 0 | 0 | 91.1 | 7.2
09:01:42 | 11.762 | 0 | 0 | 64.1 | 18.4 | 12.501 | 0 | 0 | 77.4 | 8.8
09:01:47 | 11.762 | 0 | 0 | 59.5 | 18.4 | 12.501 | 0 | 0 | 77.4 | 8.8
09:01:56 | 11.762 | 0 | 0 | 55 | 18.4 | 12.078 | 0.049 | 0.6 | 77.4 | 7.2
09:02:01 | 11.763 | 0 | 0 | 64.1 | 18.4 | 12.078 | 0.049 | 0.6 | 86.5 | 8
09:02:06 | 11.763 | 0 | 0 | 59.5 | 22.4 | 12.078 | 0.049 | 0.6 | 91.1 | 8
09:02:12 | 11.762 | 0 | 0 | 64.1 | 19.2 | 12.078 | 0.049 | 0.6 | 86.5 | 8.8
09:02:17 | 11.762 | 0 | 0 | 55 | 21.6 | 12.078 | 0.049 | 0.6 | 91.1 | 8
09:02:26 | 11.762 | 0 | 0 | 55 | 16.8 | 12.07 | 0.1 | 1.2 | 86.5 | 7.2
09:02:31 | 11.764 | 0 | 0 | 59.5 | 17.6 | 12.071 | 0.1 | 1.2 | 86.5 | 7.2
09:02:37 | 11.763 | 0 | 0 | 59.5 | 20.8 | 12.07 | 0.1 | 1.2 | 91.1 | 8
09:02:42 | 11.764 | 0 | 0 | 55 | 16.8 | 12.07 | 0.1 | 1.2 | 82 | 8
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

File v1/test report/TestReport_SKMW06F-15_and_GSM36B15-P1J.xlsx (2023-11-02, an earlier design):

time | voltage1 | current1 | power1 | vpp1 | vpp(lpf100k)1 | voltage2 | current2 | power2 | vpp2 | vpp(lpf100k)2
12:33:36 | 12.342 | 0 | 0 | 32.1 | 4.8 | 12.048 | 0 | 0 | 36.4 | 4.8
12:33:40 | 12.342 | 0 | 0 | 36.6 | 4 | 12.047 | 0 | 0 | 36.4 | 4
12:33:44 | 12.342 | 0 | 0 | 32.1 | 4 | 12.047 | 0 | 0 | 36.4 | 4.8
12:33:48 | 12.342 | 0 | 0 | 36.6 | 4.8 | 12.047 | 0 | 0 | 36.4 | 4.8
12:33:52 | 12.342 | 0 | 0 | 32.1 | 4 | 12.048 | 0 | 0 | 36.4 | 4.8
12:34:00 | 12.342 | 0 | 0 | 32.1 | 4.8 | 12.04 | 0.049 | 0.59 | 31.9 | 5.6
12:34:04 | 12.342 | 0 | 0 | 27.5 | 4.8 | 12.04 | 0.049 | 0.59 | 31.9 | 4
12:34:08 | 12.342 | 0 | 0 | 36.6 | 5.6 | 12.04 | 0.049 | 0.59 | 31.9 | 4
12:34:12 | 12.342 | 0 | 0 | 32.1 | 4 | 12.04 | 0.049 | 0.59 | 36.4 | 4.8
12:34:17 | 12.342 | 0 | 0 | 36.6 | 4 | 12.04 | 0.049 | 0.59 | 31.9 | 4.8
12:34:24 | 12.342 | 0 | 0 | 32.1 | 4 | 12.033 | 0.1 | 1.2 | 31.9 | 4
12:34:28 | 12.342 | 0 | 0 | 27.5 | 4.8 | 12.033 | 0.1 | 1.2 | 31.9 | 5.6
12:34:33 | 12.342 | 0 | 0 | 27.5 | 4.8 | 12.033 | 0.1 | 1.2 | 31.9 | 4.8
12:34:38 | 12.342 | 0 | 0 | 32.1 | 4 | 12.033 | 0.1 | 1.2 | 36.4 | 4.8
12:34:42 | 12.342 | 0 | 0 | 32.1 | 4.8 | 12.033 | 0.1 | 1.2 | 31.9 | 4.8
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

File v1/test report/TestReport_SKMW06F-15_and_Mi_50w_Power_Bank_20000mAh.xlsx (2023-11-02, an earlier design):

time | voltage1 | current1 | power1 | vpp1 | vpp(lpf100k)1 | voltage2 | current2 | power2 | vpp2 | vpp(lpf100k)2
14:59:25 | 12.345 | 0 | 0 | 32.1 | 4 | 12.048 | 0 | 0 | 41 | 4.8
14:59:30 | 12.344 | 0 | 0 | 36.6 | 4 | 12.048 | 0 | 0 | 31.9 | 4.8
14:59:35 | 12.344 | 0 | 0 | 36.6 | 4.8 | 12.048 | 0 | 0 | 36.4 | 4
14:59:39 | 12.344 | 0 | 0 | 36.6 | 4.8 | 12.048 | 0 | 0 | 36.4 | 4.8
14:59:44 | 12.344 | 0 | 0 | 36.6 | 4.8 | 12.048 | 0 | 0 | 36.4 | 4.8
14:59:51 | 12.345 | 0 | 0 | 32.1 | 4.8 | 12.04 | 0.049 | 0.59 | 36.4 | 4
14:59:56 | 12.344 | 0 | 0 | 32.1 | 4.8 | 12.04 | 0.049 | 0.59 | 31.9 | 4.8
15:00:00 | 12.344 | 0 | 0 | 32.1 | 4.8 | 12.04 | 0.049 | 0.59 | 31.9 | 4.8
15:00:04 | 12.344 | 0 | 0 | 27.5 | 4.8 | 12.04 | 0.049 | 0.59 | 31.9 | 4
15:00:08 | 12.344 | 0 | 0 | 32.1 | 4.8 | 12.04 | 0.049 | 0.59 | 31.9 | 4
15:00:16 | 12.345 | 0 | 0 | 32.1 | 4.8 | 12.033 | 0.1 | 1.2 | 31.9 | 4.8
15:00:21 | 12.344 | 0 | 0 | 27.5 | 5.6 | 12.033 | 0.1 | 1.2 | 31.9 | 4
15:00:25 | 12.344 | 0 | 0 | 27.5 | 4.8 | 12.033 | 0.1 | 1.2 | 31.9 | 4
15:00:29 | 12.344 | 0 | 0 | 27.5 | 5.6 | 12.034 | 0.1 | 1.2 | 31.9 | 4.8
15:00:33 | 12.344 | 0 | 0 | 27.5 | 4.8 | 12.033 | 0.1 | 1.2 | 31.9 | 4.8
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

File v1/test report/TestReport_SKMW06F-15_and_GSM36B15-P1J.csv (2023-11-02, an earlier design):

time | voltage1 | current1 | power1 | vpp1 | vpp(lpf100k)1 | voltage2 | current2 | power2 | vpp2 | vpp(lpf100k)2
12:33:36 | 12.342 | 0 | 0 | 32.1 | 4.8 | 12.048 | 0 | 0 | 36.4 | 4.8
12:33:40 | 12.342 | 0 | 0 | 36.6 | 4 | 12.047 | 0 | 0 | 36.4 | 4
12:33:44 | 12.342 | 0 | 0 | 32.1 | 4 | 12.047 | 0 | 0 | 36.4 | 4.8
12:33:48 | 12.342 | 0 | 0 | 36.6 | 4.8 | 12.047 | 0 | 0 | 36.4 | 4.8
12:33:52 | 12.342 | 0 | 0 | 32.1 | 4 | 12.048 | 0 | 0 | 36.4 | 4.8
12:34:00 | 12.342 | 0 | 0 | 32.1 | 4.8 | 12.04 | 0.049 | 0.59 | 31.9 | 5.6
12:34:04 | 12.342 | 0 | 0 | 27.5 | 4.8 | 12.04 | 0.049 | 0.59 | 31.9 | 4
12:34:08 | 12.342 | 0 | 0 | 36.6 | 5.6 | 12.04 | 0.049 | 0.59 | 31.9 | 4
12:34:12 | 12.342 | 0 | 0 | 32.1 | 4 | 12.04 | 0.049 | 0.59 | 36.4 | 4.8
12:34:17 | 12.342 | 0 | 0 | 36.6 | 4 | 12.04 | 0.049 | 0.59 | 31.9 | 4.8
12:34:24 | 12.342 | 0 | 0 | 32.1 | 4 | 12.033 | 0.1 | 1.2 | 31.9 | 4
12:34:28 | 12.342 | 0 | 0 | 27.5 | 4.8 | 12.033 | 0.1 | 1.2 | 31.9 | 5.6
12:34:33 | 12.342 | 0 | 0 | 27.5 | 4.8 | 12.033 | 0.1 | 1.2 | 31.9 | 4.8
12:34:38 | 12.342 | 0 | 0 | 32.1 | 4 | 12.033 | 0.1 | 1.2 | 36.4 | 4.8
12:34:42 | 12.342 | 0 | 0 | 32.1 | 4.8 | 12.033 | 0.1 | 1.2 | 31.9 | 4.8
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

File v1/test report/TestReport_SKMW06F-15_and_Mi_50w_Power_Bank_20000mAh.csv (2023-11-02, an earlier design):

time | voltage1 | current1 | power1 | vpp1 | vpp(lpf100k)1 | voltage2 | current2 | power2 | vpp2 | vpp(lpf100k)2
14:59:25 | 12.345 | 0.000 | 0.000 | 32.1 | 4.0 | 12.048 | 0.000 | 0.000 | 41.0 | 4.8
14:59:30 | 12.344 | 0.000 | 0.000 | 36.6 | 4.0 | 12.048 | 0.000 | 0.000 | 31.9 | 4.8
14:59:35 | 12.344 | 0.000 | 0.000 | 36.6 | 4.8 | 12.048 | 0.000 | 0.000 | 36.4 | 4.0
14:59:39 | 12.344 | 0.000 | 0.000 | 36.6 | 4.8 | 12.048 | 0.000 | 0.000 | 36.4 | 4.8
14:59:44 | 12.344 | 0.000 | 0.000 | 36.6 | 4.8 | 12.048 | 0.000 | 0.000 | 36.4 | 4.8
14:59:51 | 12.345 | 0.000 | 0.000 | 32.1 | 4.8 | 12.040 | 0.049 | 0.590 | 36.4 | 4.0
14:59:56 | 12.344 | 0.000 | 0.000 | 32.1 | 4.8 | 12.040 | 0.049 | 0.590 | 31.9 | 4.8
15:00:00 | 12.344 | 0.000 | 0.000 | 32.1 | 4.8 | 12.040 | 0.049 | 0.590 | 31.9 | 4.8
15:00:04 | 12.344 | 0.000 | 0.000 | 27.5 | 4.8 | 12.040 | 0.049 | 0.590 | 31.9 | 4.0
15:00:08 | 12.344 | 0.000 | 0.000 | 32.1 | 4.8 | 12.040 | 0.049 | 0.590 | 31.9 | 4.0
15:00:16 | 12.345 | 0.000 | 0.000 | 32.1 | 4.8 | 12.033 | 0.100 | 1.200 | 31.9 | 4.8
15:00:21 | 12.344 | 0.000 | 0.000 | 27.5 | 5.6 | 12.033 | 0.100 | 1.200 | 31.9 | 4.0
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

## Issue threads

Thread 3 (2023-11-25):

Plans on additional rack variants using 1U rows

fxwiegand, 2023-11-25:
Hey 👋🏻

Many thanks for creating these amazing cases they certainly do look very good and the documentation is outstanding! Do you plan to add other case variants with 1U rows as well? This would definitely be interesting to me and probably others as well!

Best greetings!

Felix from [wgd modular](https://www.instagram.com/wgdmodular/)

KevinKeWang, 2023-11-27:
Hello!

I won't be considering adding 1U track in the near future. as I don't think it looks too coherent on a 2x44hp.
It is possible to add 1U track to a single row of small boxes. you can make a simple modification via plasticity. I have uploaded the plasticity source project file. Similarly, modifying the width of the boxes via plasticity is very simple.

Thank you for your support!

KevinKeWang, 2023-11-27:
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

Hello!

I won't be considering adding 1U track in the near future. as I don't think it looks too coherent on a 2x44hp.
It is possible to add 1U track to a single row of small boxes. you can make a simple modification via plasticity. I have uploaded the plasticity source project file. Similarly, modifying the width of the boxes via plasticity is very simple.

Thank you for your support!

Closed 2024-05-05.

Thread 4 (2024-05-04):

Shallower version of 2x44HP rack

jhbruhn, 2024-05-04:
Hi! Really awesome design of cases and incredibly well documented!!

The 2x44HP Rack currently has quite a lot of space behind the modules. For Setups with mostly SMD-based modules with a single PCB, it could be made more compact. I tried to reduce the depth in the plasticity files (thanks for providing), but utterly failed. Did I miss some parameter setting somewhere, or a central sketch view?

Thanks a bunch!

KevinKeWang, 2024-05-05:
> tried

The plasticity file is fully editable. What is the exact problem?

KevinKeWang, 2024-05-05:
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

The plasticity file is fully editable. What is the exact problem?

Closed 2024-07-22.

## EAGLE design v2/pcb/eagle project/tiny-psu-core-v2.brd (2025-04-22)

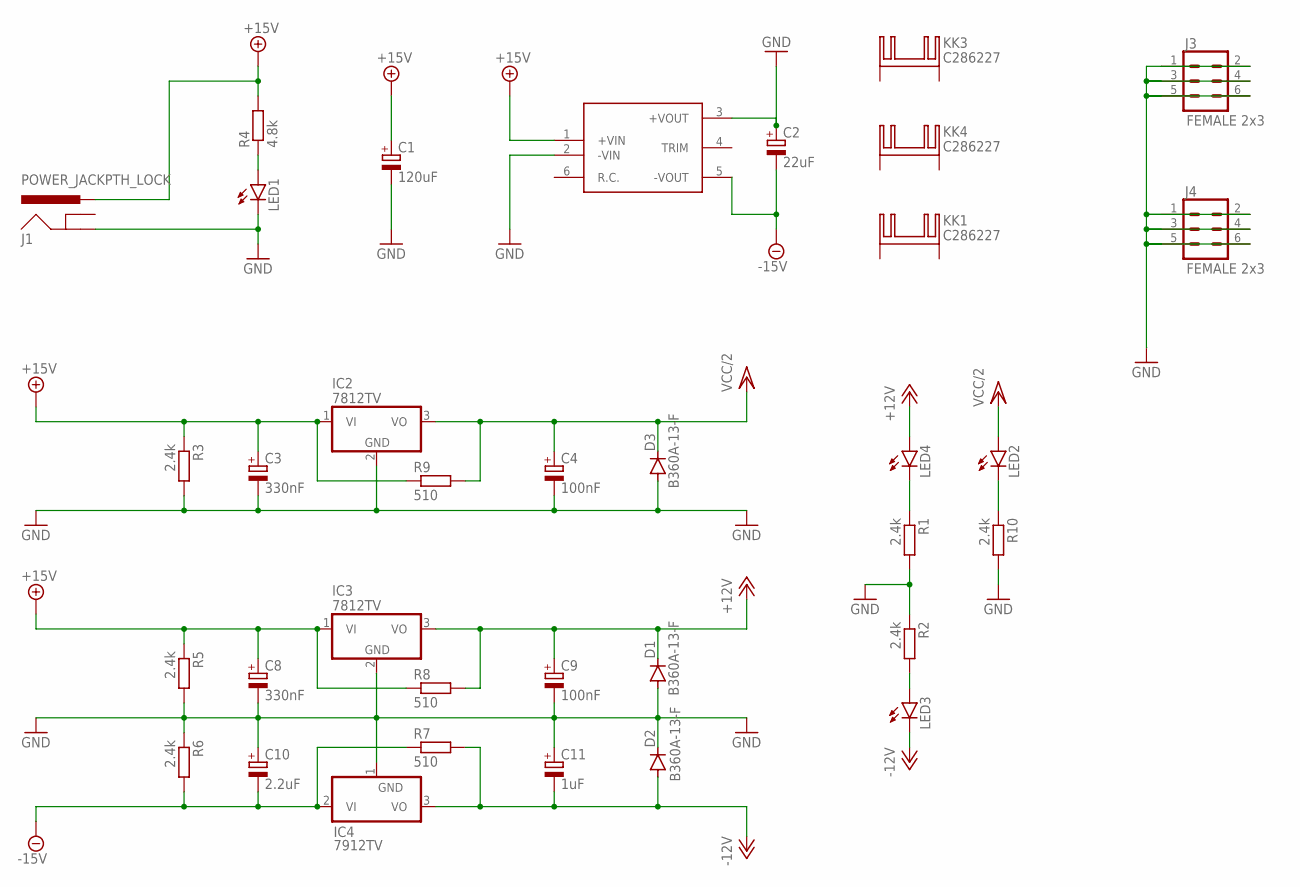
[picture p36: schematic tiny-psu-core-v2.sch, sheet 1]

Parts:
C1: 120uF; E5-10,5
C2: 22uF; E2,5-6
C3, C8: 330nF; CAPMP3216X180N
C4, C9: 100nF; CAPMP3216X180N
C10: 2.2uF; CAPMP3528X210N
C11: 1uF; CAPMP3216X180N
D1, D2, D3: B360A-13-F; DO-214AC
IC1: SKMW
IC2, IC3: 7812TV; TO220V
IC4: 7912TV; TO220V
J1: POWER_JACKPTH_LOCK; POWER_JACK_PTH_LOCK
J3, J4: FEMALE 2x3; 2X3
KK1, KK3, KK4: C286227
LED1, LED2, LED3, LED4: LEDCHIP-LED0805; CHIP-LED0805
R1, R2, R3, R5, R6, R10: 2.4k; R0805
R4: 4.8k; R0805
R7, R8, R9: 510; R0805

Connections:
+12V: C9.1 (+), D1.C, IC3.3 (VO), LED4.A, R8.2; also elsewhere on the board
+15V: C1.+, C3.1 (+), C8.1 (+), IC1.1 (+VIN), IC2.1 (VI), IC3.1 (VI), J1.PWR, R3.1, R4.2, R5.1, R8.1, R9.1; also elsewhere on the board
-12V: C11.2 (-), D2.A, IC4.3 (VO), LED3.C, R7.2; also elsewhere on the board
-15V: C2.-, C10.2 (-), IC1.5 (-VOUT), IC4.2 (VI), R6.2, R7.1
GND: C1.-, C2.+, C3.2 (-), C4.2 (-), C8.2 (-), C9.2 (-), C10.1 (+), C11.1 (+), D1.A, D2.C, D3.A, IC1.2 (-VIN), IC1.3 (+VOUT), IC2.2 (GND), IC3.2 (GND), IC4.1 (GND), J1.GND, J3.1, J3.2, J3.3, J3.4, J3.5, J3.6, J4.1, J4.2, J4.3, J4.4, J4.5, J4.6, LED1.C, R1.2, R2.1, R3.2, R5.2, R6.1, R10.2; also elsewhere on the board
unnamed: LED4.C, R1.1
unnamed: LED2.C, R10.1
unnamed: LED3.A, R2.2
unnamed: LED1.A, R4.1
VCC/2: C4.1 (+), D3.C, IC2.3 (VO), LED2.A, R9.2; also elsewhere on the board

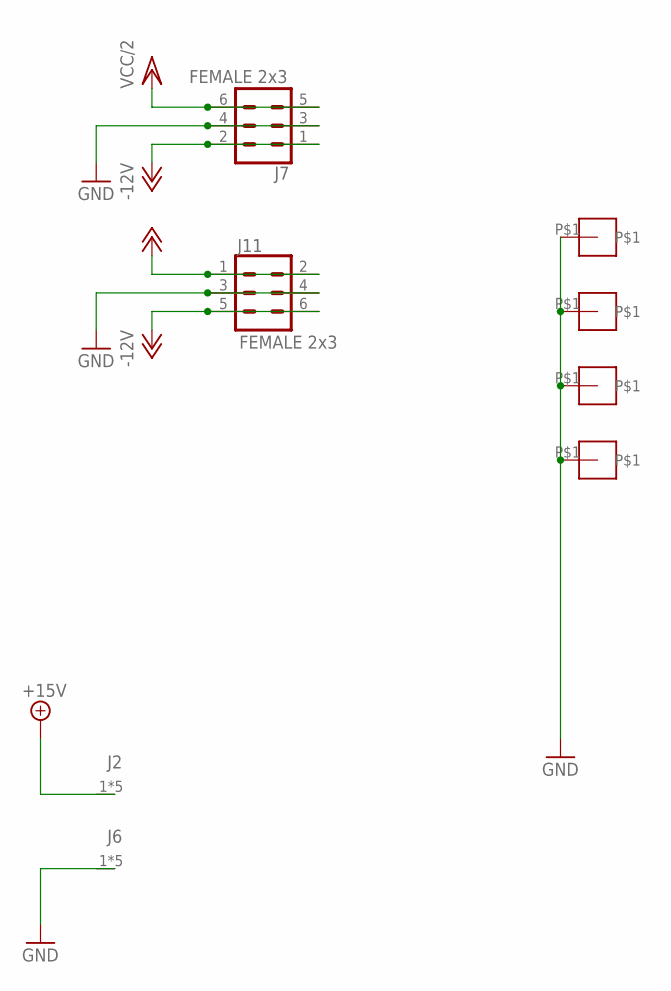
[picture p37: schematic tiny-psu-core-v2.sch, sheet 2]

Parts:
J2, J6: 30A-SCREW-CONN; 50X72
J7, J11: FEMALE 2x3; 2X3
U$3, U$4, U$5, U$6: M3-HOLE

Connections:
+12V: J11.1, J11.2; also elsewhere on the board
+15V: J2.1, J2.2, J2.3, J2.4, J2.P$1; also elsewhere on the board
-12V: J7.1, J7.2, J11.5, J11.6; also elsewhere on the board
GND: J6.1, J6.2, J6.3, J6.4, J6.P$1, J7.3, J7.4, J11.3, J11.4, U$3.P$1, U$4.P$1, U$5.P$1, U$6.P$1; also elsewhere on the board
VCC/2: J7.5, J7.6; also elsewhere on the board

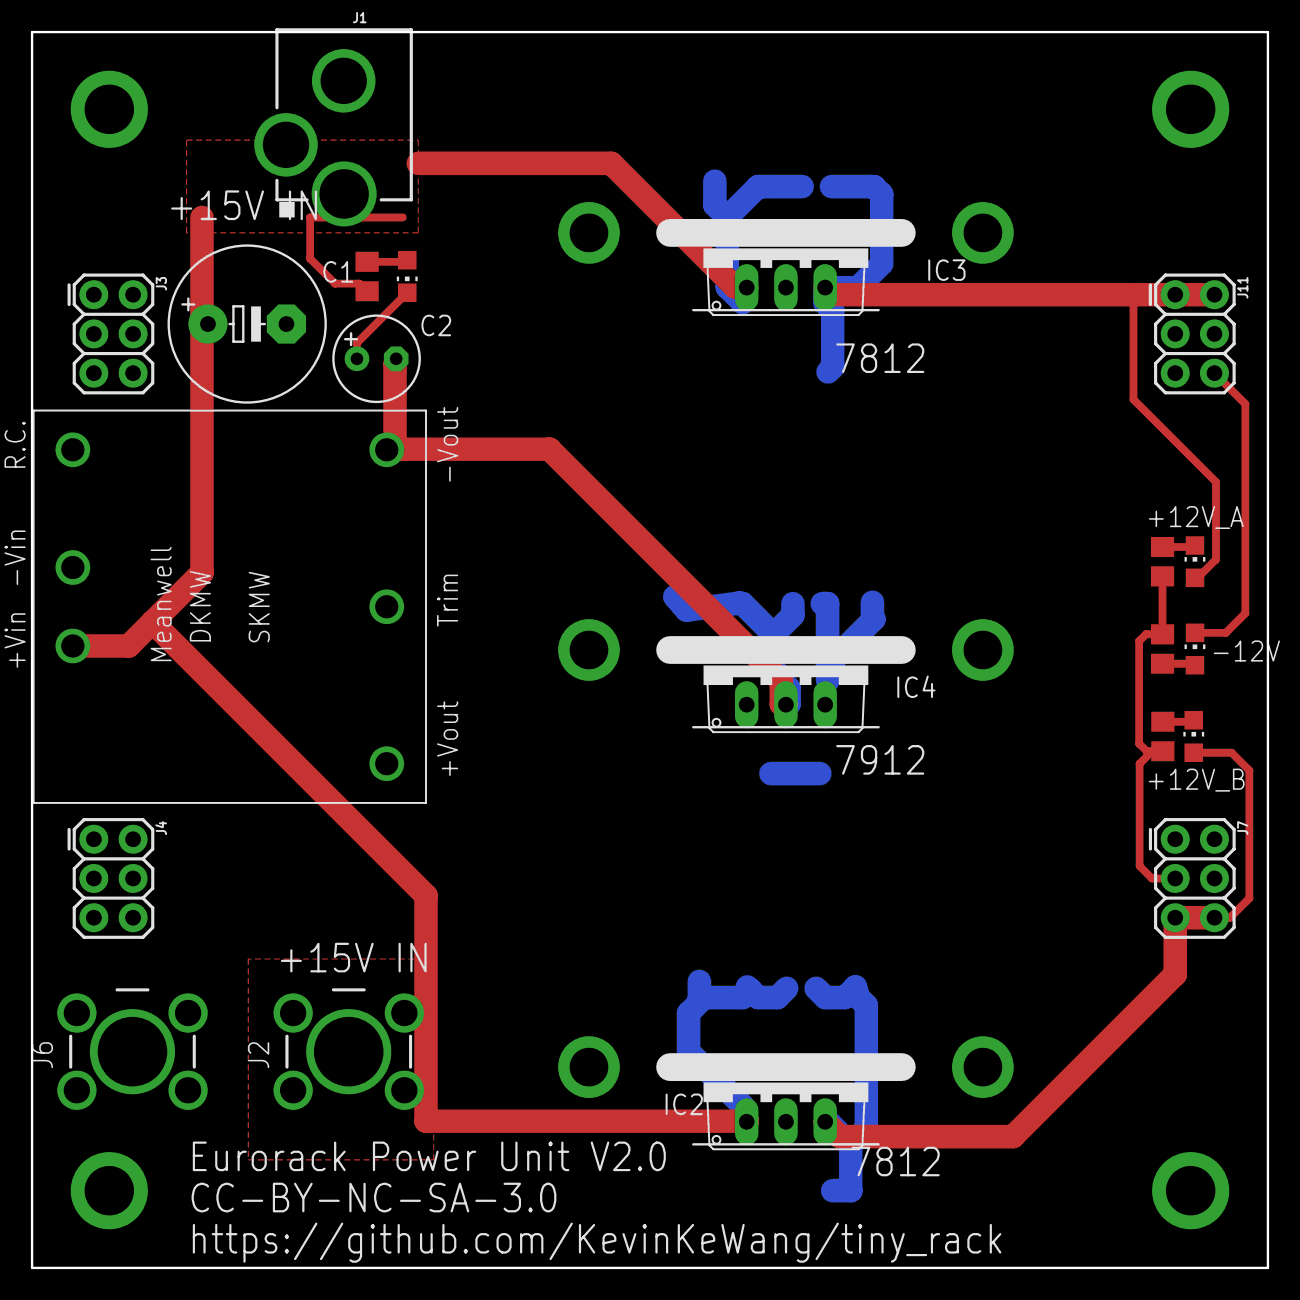
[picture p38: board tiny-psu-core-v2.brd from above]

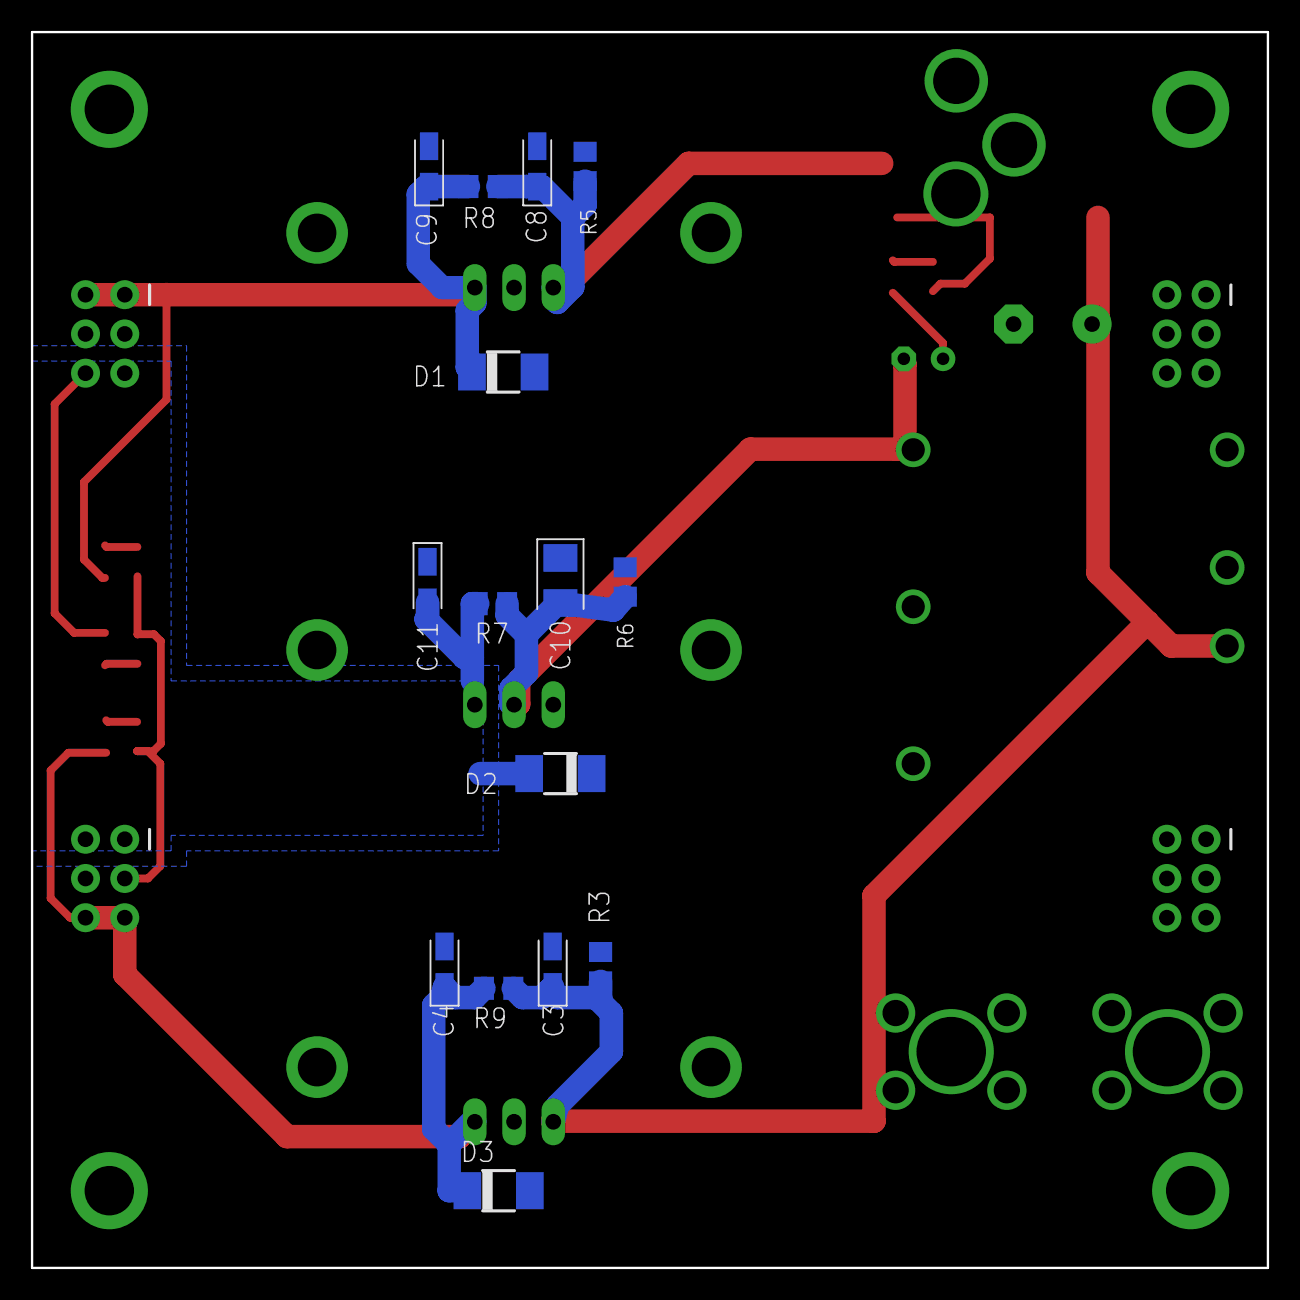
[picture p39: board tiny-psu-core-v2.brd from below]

Board: 4 copper layers, 80.0 x 80.0 mm, 43 parts (15 on the bottom side), 10 nets.

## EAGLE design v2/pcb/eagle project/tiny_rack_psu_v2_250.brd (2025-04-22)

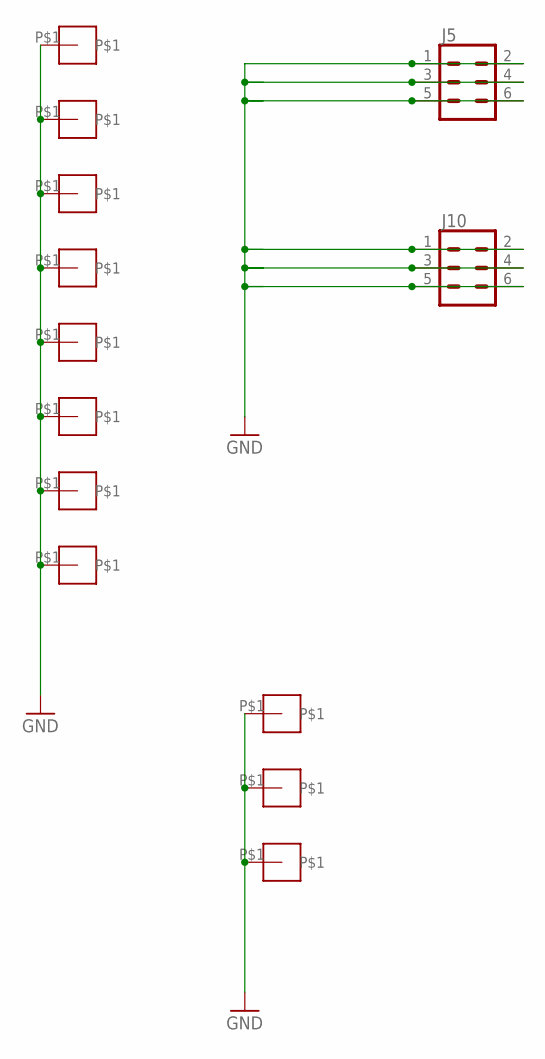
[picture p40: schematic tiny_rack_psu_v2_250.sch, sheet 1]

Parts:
J5, J10: CONN_03X2FEMALE_SMD; 2X3_SMD
U$1, U$2, U$3, U$4, U$5, U$6, U$8, U$9, U$10, U$11, U$12: M3-HOLE

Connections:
GND: J5.1, J5.2, J5.3, J5.4, J5.5, J5.6, J10.1, J10.2, J10.3, J10.4, J10.5, J10.6, U$1.P$1, U$2.P$1, U$3.P$1, U$4.P$1, U$5.P$1, U$6.P$1, U$8.P$1, U$9.P$1, U$10.P$1, U$11.P$1, U$12.P$1; also elsewhere on the board

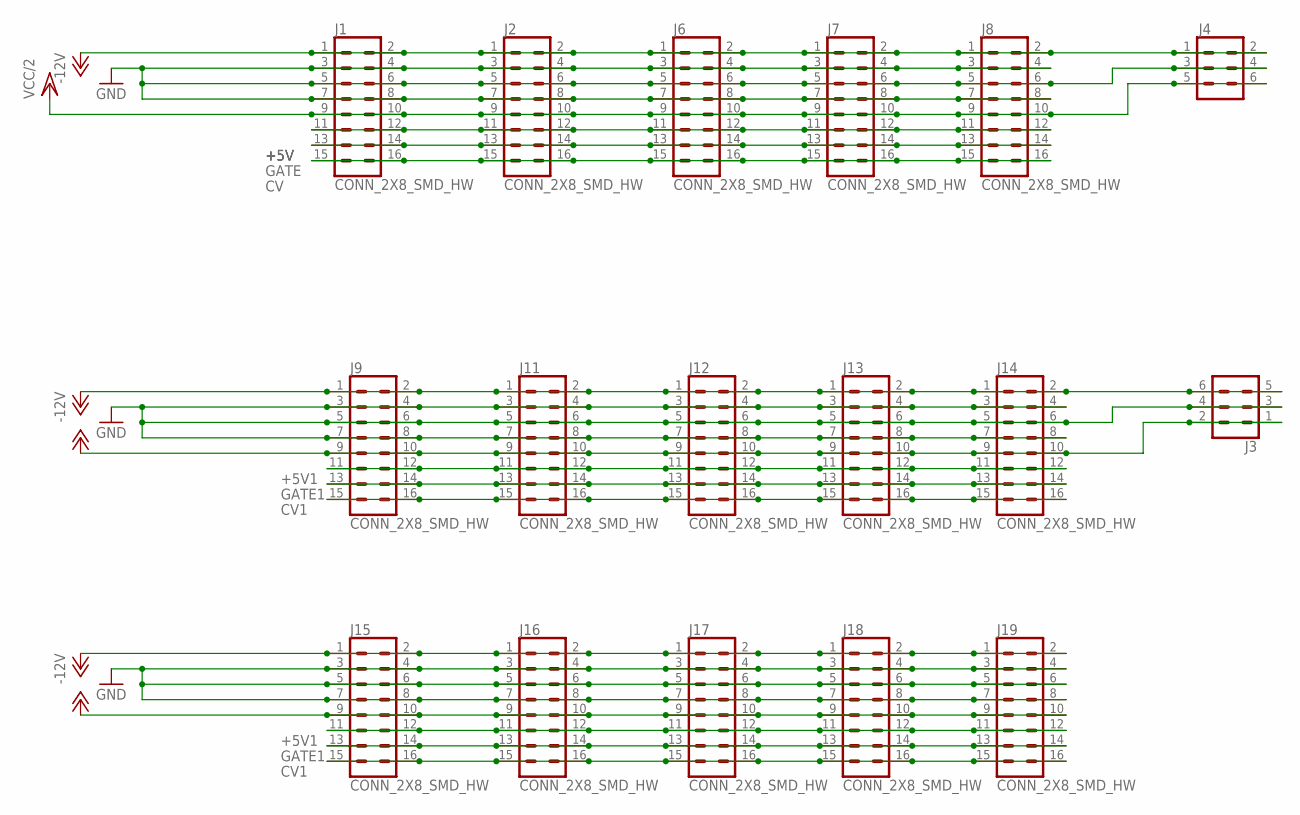
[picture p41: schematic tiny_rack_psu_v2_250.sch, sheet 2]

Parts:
J1, J2, J6, J7, J8, J9, J11, J12, J13, J14, J15, J16, J17, J18, J19: CONN_2X8_SMD_HW; 2X8-SHROUDED_SMD_HW
J3, J4: CONN_03X2FEMALE_SMD; 2X3_SMD

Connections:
+5V: J1.11, J1.12, J2.11, J2.12, J6.11, J6.12, J7.11, J7.12, J8.11, J8.12; also elsewhere on the board
+5V1: J9.11, J9.12, J11.11, J11.12, J12.11, J12.12, J13.11, J13.12, J14.11, J14.12, J15.11, J15.12, J16.11, J16.12, J17.11, J17.12, J18.11, J18.12, J19.11, J19.12; also elsewhere on the board
+12V: J3.1, J3.2, J9.9, J9.10, J11.9, J11.10, J12.9, J12.10, J13.9, J13.10, J14.9, J14.10, J15.9, J15.10, J16.9, J16.10, J17.9, J17.10, J18.9, J18.10, J19.9, J19.10; also elsewhere on the board
-12V: J1.1, J1.2, J2.1, J2.2, J3.5, J3.6, J4.1, J4.2, J6.1, J6.2, J7.1, J7.2, J8.1, J8.2, J9.1, J9.2, J11.1, J11.2, J12.1, J12.2, J13.1, J13.2, J14.1, J14.2, J15.1, J15.2, J16.1, J16.2, J17.1, J17.2, J18.1, J18.2, J19.1, J19.2; also elsewhere on the board
CV: J1.15, J1.16, J2.15, J2.16, J6.15, J6.16, J7.15, J7.16, J8.15, J8.16; also elsewhere on the board
CV1: J9.15, J9.16, J11.15, J11.16, J12.15, J12.16, J13.15, J13.16, J14.15, J14.16, J15.15, J15.16, J16.15, J16.16, J17.15, J17.16, J18.15, J18.16, J19.15, J19.16; also elsewhere on the board
GATE: J1.13, J1.14, J2.13, J2.14, J6.13, J6.14, J7.13, J7.14, J8.13, J8.14; also elsewhere on the board
GATE1: J9.13, J9.14, J11.13, J11.14, J12.13, J12.14, J13.13, J13.14, J14.13, J14.14, J15.13, J15.14, J16.13, J16.14, J17.13, J17.14, J18.13, J18.14, J19.13, J19.14; also elsewhere on the board
GND: J1.3, J1.4, J1.5, J1.6, J1.7, J1.8, J2.3, J2.4, J2.5, J2.6, J2.7, J2.8, J3.3, J3.4, J4.3, J4.4, J6.3, J6.4, J6.5, J6.6, J6.7, J6.8, J7.3, J7.4, J7.5, J7.6, J7.7, J7.8, J8.3, J8.4, J8.5, J8.6, J8.7, J8.8, J9.3, J9.4, J9.5, J9.6, J9.7, J9.8, J11.3, J11.4, J11.5, J11.6, J11.7, J11.8, J12.3, J12.4, J12.5, J12.6, J12.7, J12.8, J13.3, J13.4, J13.5, J13.6, J13.7, J13.8, J14.3, J14.4, J14.5, J14.6, J14.7, J14.8, J15.3, J15.4, J15.5, J15.6, J15.7, J15.8, J16.3, J16.4, J16.5, J16.6, J16.7, J16.8, J17.3, J17.4, J17.5, J17.6, J17.7, J17.8, J18.3, J18.4, J18.5, J18.6, J18.7, J18.8, J19.3, J19.4, J19.5, J19.6, J19.7, J19.8; also elsewhere on the board
VCC/2: J1.9, J1.10, J2.9, J2.10, J4.5, J4.6, J6.9, J6.10, J7.9, J7.10, J8.9, J8.10; also elsewhere on the board

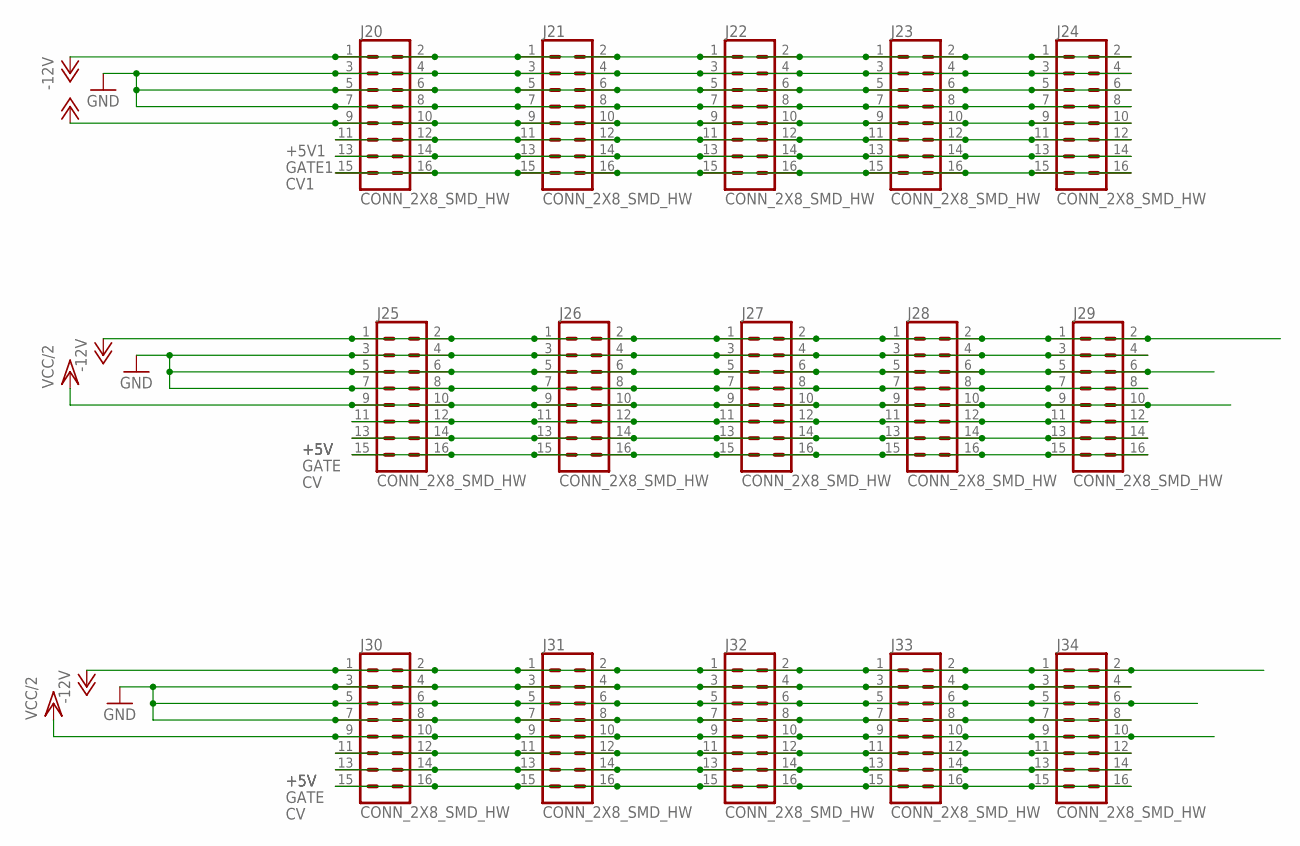
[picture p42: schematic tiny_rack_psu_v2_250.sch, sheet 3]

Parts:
J20, J21, J22, J23, J24, J25, J26, J27, J28, J29, J30, J31, J32, J33, J34: CONN_2X8_SMD_HW; 2X8-SHROUDED_SMD_HW

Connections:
+5V: J25.11, J25.12, J26.11, J26.12, J27.11, J27.12, J28.11, J28.12, J29.11, J29.12, J30.11, J30.12, J31.11, J31.12, J32.11, J32.12, J33.11, J33.12, J34.11, J34.12; also elsewhere on the board
+5V1: J20.11, J20.12, J21.11, J21.12, J22.11, J22.12, J23.11, J23.12, J24.11, J24.12; also elsewhere on the board
+12V: J20.9, J20.10, J21.9, J21.10, J22.9, J22.10, J23.9, J23.10, J24.9, J24.10; also elsewhere on the board
-12V: J20.1, J20.2, J21.1, J21.2, J22.1, J22.2, J23.1, J23.2, J24.1, J24.2, J25.1, J25.2, J26.1, J26.2, J27.1, J27.2, J28.1, J28.2, J29.1, J29.2, J30.1, J30.2, J31.1, J31.2, J32.1, J32.2, J33.1, J33.2, J34.1, J34.2; also elsewhere on the board
CV: J25.15, J25.16, J26.15, J26.16, J27.15, J27.16, J28.15, J28.16, J29.15, J29.16, J30.15, J30.16, J31.15, J31.16, J32.15, J32.16, J33.15, J33.16, J34.15, J34.16; also elsewhere on the board
CV1: J20.15, J20.16, J21.15, J21.16, J22.15, J22.16, J23.15, J23.16, J24.15, J24.16; also elsewhere on the board
GATE: J25.13, J25.14, J26.13, J26.14, J27.13, J27.14, J28.13, J28.14, J29.13, J29.14, J30.13, J30.14, J31.13, J31.14, J32.13, J32.14, J33.13, J33.14, J34.13, J34.14; also elsewhere on the board
GATE1: J20.13, J20.14, J21.13, J21.14, J22.13, J22.14, J23.13, J23.14, J24.13, J24.14; also elsewhere on the board
GND: J20.3, J20.4, J20.5, J20.6, J20.7, J20.8, J21.3, J21.4, J21.5, J21.6, J21.7, J21.8, J22.3, J22.4, J22.5, J22.6, J22.7, J22.8, J23.3, J23.4, J23.5, J23.6, J23.7, J23.8, J24.3, J24.4, J24.5, J24.6, J24.7, J24.8, J25.3, J25.4, J25.5, J25.6, J25.7, J25.8, J26.3, J26.4, J26.5, J26.6, J26.7, J26.8, J27.3, J27.4, J27.5, J27.6, J27.7, J27.8, J28.3, J28.4, J28.5, J28.6, J28.7, J28.8, J29.3, J29.4, J29.5, J29.6, J29.7, J29.8, J30.3, J30.4, J30.5, J30.6, J30.7, J30.8, J31.3, J31.4, J31.5, J31.6, J31.7, J31.8, J32.3, J32.4, J32.5, J32.6, J32.7, J32.8, J33.3, J33.4, J33.5, J33.6, J33.7, J33.8, J34.3, J34.4, J34.5, J34.6, J34.7, J34.8; also elsewhere on the board
VCC/2: J25.9, J25.10, J26.9, J26.10, J27.9, J27.10, J28.9, J28.10, J29.9, J29.10, J30.9, J30.10, J31.9, J31.10, J32.9, J32.10, J33.9, J33.10, J34.9, J34.10; also elsewhere on the board

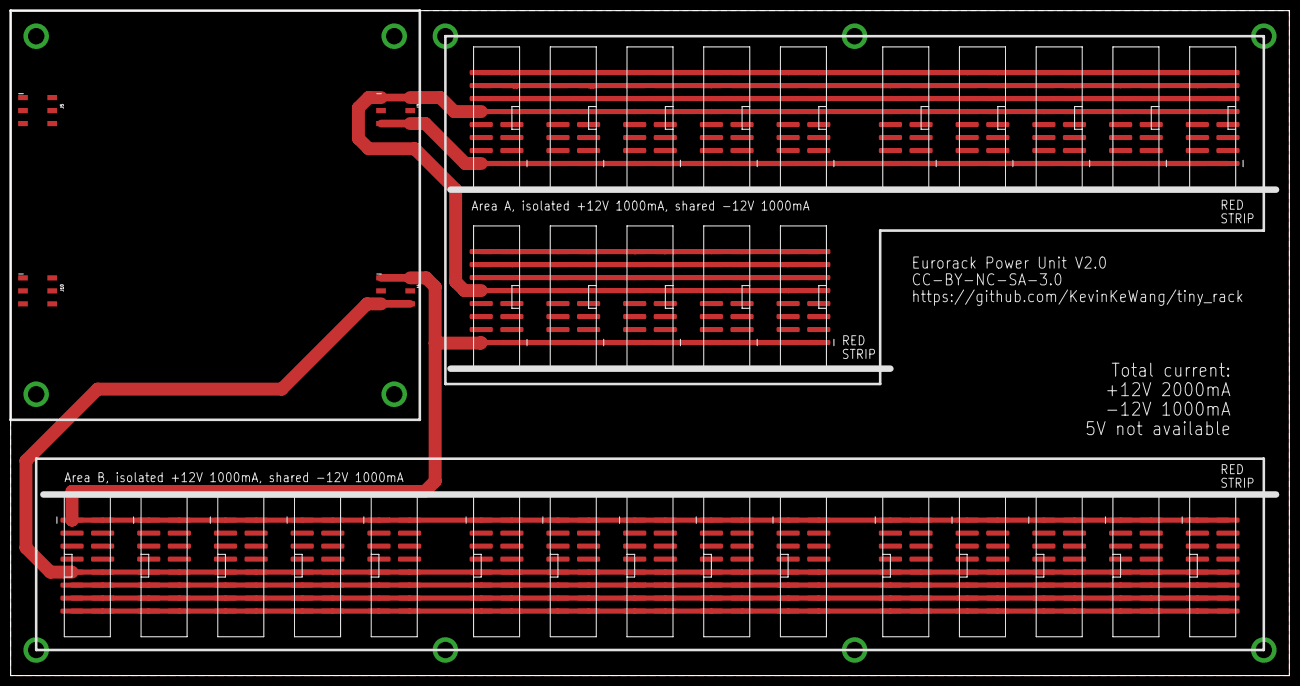
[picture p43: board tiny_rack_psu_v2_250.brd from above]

Board: 4 copper layers, 250.0 x 130.0 mm, 45 parts (0 on the bottom side), 10 nets.

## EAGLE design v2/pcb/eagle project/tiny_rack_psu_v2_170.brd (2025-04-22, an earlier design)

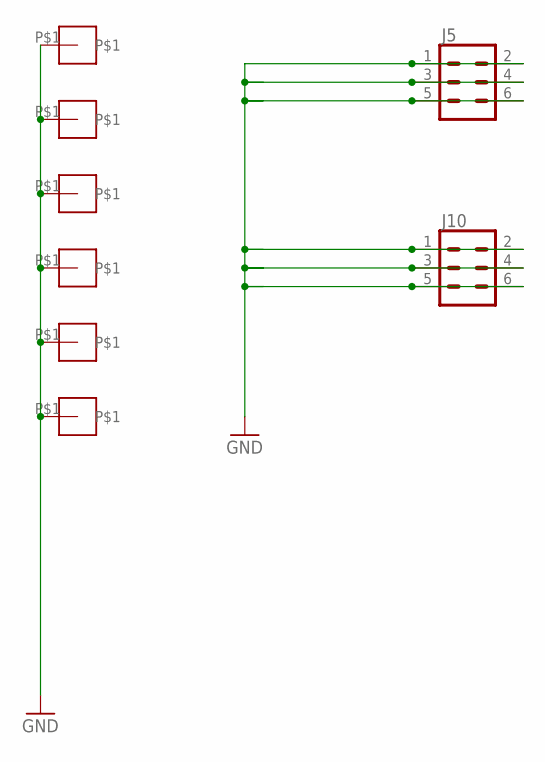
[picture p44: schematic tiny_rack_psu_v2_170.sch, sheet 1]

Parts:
J5, J10: CONN_03X2FEMALE_SMD; 2X3_SMD
U$1, U$2, U$3, U$4, U$5, U$6: M3-HOLE

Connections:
GND: J5.1, J5.2, J5.3, J5.4, J5.5, J5.6, J10.1, J10.2, J10.3, J10.4, J10.5, J10.6, U$1.P$1, U$2.P$1, U$3.P$1, U$4.P$1, U$5.P$1, U$6.P$1; also elsewhere on the board

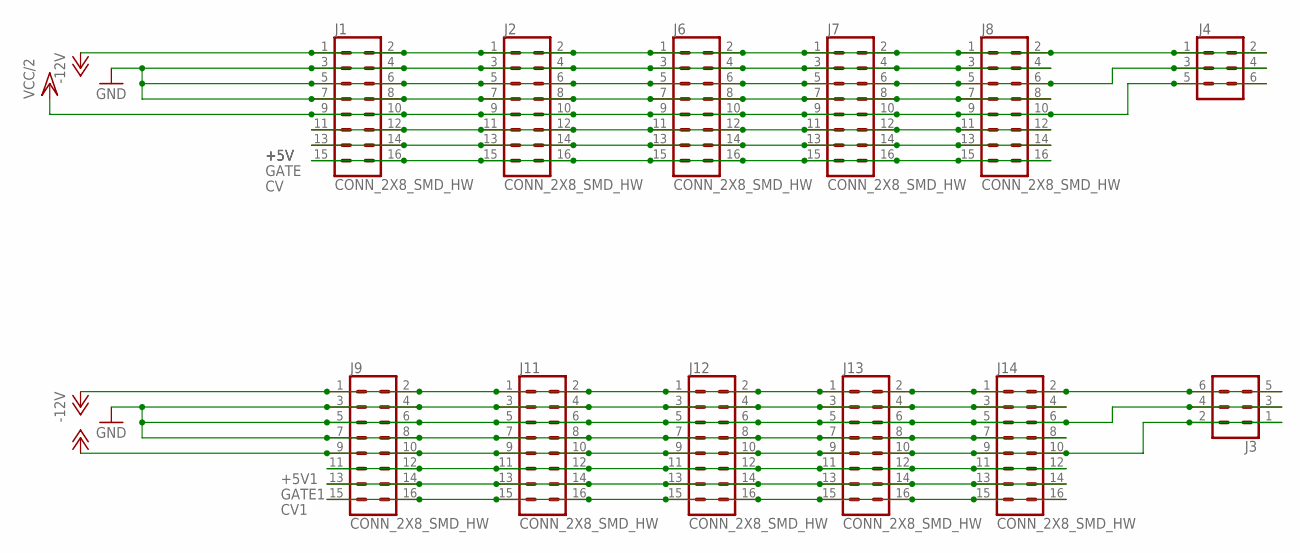
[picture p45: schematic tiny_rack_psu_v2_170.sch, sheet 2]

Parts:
J1, J2, J6, J7, J8, J9, J11, J12, J13, J14: CONN_2X8_SMD_HW; 2X8-SHROUDED_SMD_HW
J3, J4: CONN_03X2FEMALE_SMD; 2X3_SMD

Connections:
+5V: J1.11, J1.12, J2.11, J2.12, J6.11, J6.12, J7.11, J7.12, J8.11, J8.12
+5V1: J9.11, J9.12, J11.11, J11.12, J12.11, J12.12, J13.11, J13.12, J14.11, J14.12
+12V: J3.1, J3.2, J9.9, J9.10, J11.9, J11.10, J12.9, J12.10, J13.9, J13.10, J14.9, J14.10
-12V: J1.1, J1.2, J2.1, J2.2, J3.5, J3.6, J4.1, J4.2, J6.1, J6.2, J7.1, J7.2, J8.1, J8.2, J9.1, J9.2, J11.1, J11.2, J12.1, J12.2, J13.1, J13.2, J14.1, J14.2
CV: J1.15, J1.16, J2.15, J2.16, J6.15, J6.16, J7.15, J7.16, J8.15, J8.16
CV1: J9.15, J9.16, J11.15, J11.16, J12.15, J12.16, J13.15, J13.16, J14.15, J14.16
GATE: J1.13, J1.14, J2.13, J2.14, J6.13, J6.14, J7.13, J7.14, J8.13, J8.14
GATE1: J9.13, J9.14, J11.13, J11.14, J12.13, J12.14, J13.13, J13.14, J14.13, J14.14
GND: J1.3, J1.4, J1.5, J1.6, J1.7, J1.8, J2.3, J2.4, J2.5, J2.6, J2.7, J2.8, J3.3, J3.4, J4.3, J4.4, J6.3, J6.4, J6.5, J6.6, J6.7, J6.8, J7.3, J7.4, J7.5, J7.6, J7.7, J7.8, J8.3, J8.4, J8.5, J8.6, J8.7, J8.8, J9.3, J9.4, J9.5, J9.6, J9.7, J9.8, J11.3, J11.4, J11.5, J11.6, J11.7, J11.8, J12.3, J12.4, J12.5, J12.6, J12.7, J12.8, J13.3, J13.4, J13.5, J13.6, J13.7, J13.8, J14.3, J14.4, J14.5, J14.6, J14.7, J14.8; also elsewhere on the board
VCC/2: J1.9, J1.10, J2.9, J2.10, J4.5, J4.6, J6.9, J6.10, J7.9, J7.10, J8.9, J8.10

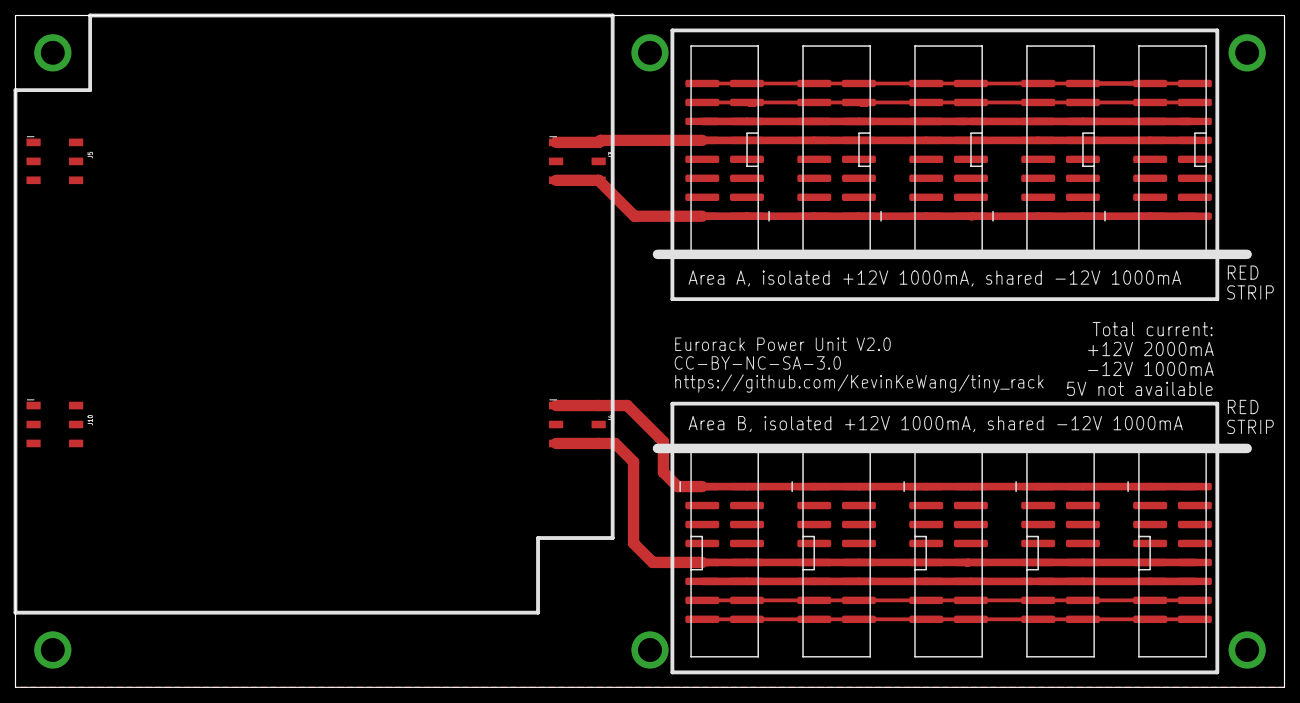
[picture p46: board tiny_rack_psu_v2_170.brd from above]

Board: 4 copper layers, 170.0 x 90.0 mm, 20 parts (0 on the bottom side), 10 nets.

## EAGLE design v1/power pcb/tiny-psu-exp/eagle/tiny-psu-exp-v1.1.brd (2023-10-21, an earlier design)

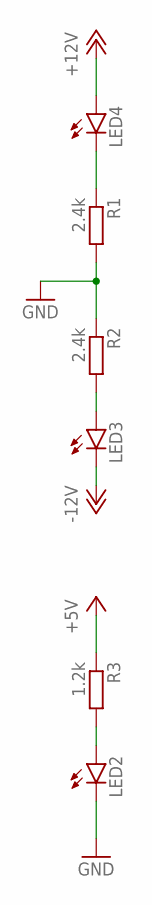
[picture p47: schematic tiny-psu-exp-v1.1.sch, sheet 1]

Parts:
LED2, LED3, LED4: LEDCHIP-LED0805; CHIP-LED0805
R1, R2: 2.4k; R0805
R3: 1.2k; R0805

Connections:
+5V: R3.1; also elsewhere on the board
+12V: LED4.A; also elsewhere on the board
-12V: LED3.C; also elsewhere on the board
GND: LED2.C, R1.2, R2.1; also elsewhere on the board
unnamed: LED4.C, R1.1
unnamed: LED3.A, R2.2
unnamed: LED2.A, R3.2


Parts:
J1, J2, J3, J4, J6, J7, J8, J9, J10, J11, J12, J13: 30A-SCREW-CONN; 50X72
X1, X4, X5, X6, X7, X8, X9, X10, X11, X13, X15, X17, X18, X19, X20: 057-016-10; 057-016-1

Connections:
+5V: J1.1, J1.2, J1.3, J1.4, J1.P$1, J2.1, J2.2, J2.3, J2.4, J2.P$1, X1.11, X1.12, X4.11, X4.12, X5.11, X5.12, X6.11, X6.12, X7.11, X7.12, X8.11, X8.12, X9.11, X9.12, X10.11, X10.12, X11.11, X11.12, X13.11, X13.12, X15.11, X15.12, X17.11, X17.12, X18.11, X18.12, X19.11, X19.12, X20.11, X20.12; also elsewhere on the board
+12V: J4.1, J4.2, J4.3, J4.4, J4.P$1, J8.1, J8.2, J8.3, J8.4, J8.P$1, X1.9, X1.10, X4.9, X4.10, X5.9, X5.10, X6.9, X6.10, X7.9, X7.10, X8.9, X8.10, X9.9, X9.10, X10.9, X10.10, X11.9, X11.10, X13.9, X13.10, X15.9, X15.10, X17.9, X17.10, X18.9, X18.10, X19.9, X19.10, X20.9, X20.10; also elsewhere on the board
-12V: J11.1, J11.2, J11.3, J11.4, J11.P$1, J13.1, J13.2, J13.3, J13.4, J13.P$1, X1.1, X1.2, X4.1, X4.2, X5.1, X5.2, X6.1, X6.2, X7.1, X7.2, X8.1, X8.2, X9.1, X9.2, X10.1, X10.2, X11.1, X11.2, X13.1, X13.2, X15.1, X15.2, X17.1, X17.2, X18.1, X18.2, X19.1, X19.2, X20.1, X20.2; also elsewhere on the board
CV1: X1.13, X1.14, X4.13, X4.14, X5.13, X5.14, X6.13, X6.14, X7.13, X7.14, X8.13, X8.14, X9.13, X9.14, X10.13, X10.14, X11.13, X11.14, X13.13, X13.14, X15.13, X15.14, X17.13, X17.14, X18.13, X18.14, X19.13, X19.14, X20.13, X20.14
GATE1: X1.15, X1.16, X4.15, X4.16, X5.15, X5.16, X6.15, X6.16, X7.15, X7.16, X8.15, X8.16, X9.15, X9.16, X10.15, X10.16, X11.15, X11.16, X13.15, X13.16, X15.15, X15.16, X17.15, X17.16, X18.15, X18.16, X19.15, X19.16, X20.15, X20.16
GND: J3.1, J3.2, J3.3, J3.4, J3.P$1, J6.1, J6.2, J6.3, J6.4, J6.P$1, J7.1, J7.2, J7.3, J7.4, J7.P$1, J9.1, J9.2, J9.3, J9.4, J9.P$1, J10.1, J10.2, J10.3, J10.4, J10.P$1, J12.1, J12.2, J12.3, J12.4, J12.P$1, X1.3, X1.4, X1.5, X1.6, X1.7, X1.8, X4.3, X4.4, X4.5, X4.6, X4.7, X4.8, X5.3, X5.4, X5.5, X5.6, X5.7, X5.8, X6.3, X6.4, X6.5, X6.6, X6.7, X6.8, X7.3, X7.4, X7.5, X7.6, X7.7, X7.8, X8.3, X8.4, X8.5, X8.6, X8.7, X8.8, X9.3, X9.4, X9.5, X9.6, X9.7, X9.8, X10.3, X10.4, X10.5, X10.6, X10.7, X10.8, X11.3, X11.4, X11.5, X11.6, X11.7, X11.8, X13.3, X13.4, X13.5, X13.6, X13.7, X13.8, X15.3, X15.4, X15.5, X15.6, X15.7, X15.8, X17.3, X17.4, X17.5, X17.6, X17.7, X17.8, X18.3, X18.4, X18.5, X18.6, X18.7, X18.8, X19.3, X19.4, X19.5, X19.6, X19.7, X19.8, X20.3, X20.4, X20.5, X20.6, X20.7, X20.8; also elsewhere on the board



Board: 4 copper layers, 90.0 x 90.0 mm, 33 parts (6 on the bottom side), 9 nets.

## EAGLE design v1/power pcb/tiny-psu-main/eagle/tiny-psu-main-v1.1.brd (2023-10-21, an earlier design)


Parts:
C1: 120uF; E5-10,5
C2, C6: 22uF; E2,5-6
C8: 330nF; CAPMP3216X180N
C9: 100nF; CAPMP3216X180N
C10: 2.2uF; CAPMP3528X210N
C11: 1uF; CAPMP3216X180N
D1, D2: B360A-13-F; DO-214AC
IC1: SKMW
IC2: NID100-5; NID65-HORIZONTAL
IC3: 7812TV; TO220V
IC4: 7912TV; TO220V
J7: POWER_JACKPTH_LOCK; POWER_JACK_PTH_LOCK
KK1, KK2: 4X4
KK3, KK4: C286227
LED1, LED2, LED3, LED4: LEDCHIP-LED0805; CHIP-LED0805
R1, R2, R5, R6: 2.4k; R0805
R3: 1.2k; R0805
R4: 4.8k; R0805
R7, R8: 510; R0805

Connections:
+5V: C6.+, IC2.1 (+VOUT), IC2.2 (+VOUT), IC2.3 (+VOUT), IC2.4 (+VOUT), R3.1; also elsewhere on the board
+12V: C9.1 (+), D1.C, IC3.3 (VO), LED4.A, R8.2; also elsewhere on the board
+15V: C1.+, C8.1 (+), IC1.1 (+VIN), IC2.9 (+VIN), IC2.10 (+VIN), IC3.1 (VI), J7.PWR, R4.2, R5.1, R8.1
-12V: C11.2 (-), D2.A, IC4.3 (VO), LED3.C, R7.2; also elsewhere on the board
-15V: C2.-, C10.2 (-), IC1.5 (-VOUT), IC4.2 (VI), R6.2, R7.1
GND: C1.-, C2.+, C6.-, C8.2 (-), C9.2 (-), C10.1 (+), C11.1 (+), D1.A, D2.C, IC1.2 (-VIN), IC1.3 (+VOUT), IC2.5 (COM), IC2.6 (COM), IC2.7 (COM), IC2.8 (COM), IC3.2 (GND), IC4.1 (GND), J7.GND, LED1.C, LED2.C, R1.2, R2.1, R5.2, R6.1; also elsewhere on the board
unnamed: LED4.C, R1.1
unnamed: LED3.A, R2.2
unnamed: LED1.A, R4.1
unnamed: LED2.A, R3.2


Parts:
C3, C17, C19: 22u; C1206
C15: 100n; C0402
IC5: ROF-78E3.3-0.5SMD; ROF78EXX-0.5SMD
J2, J6, J8, J9, J10, J11: 30A-SCREW-CONN; 50X72
J3: FEMALE 2x3; 2X3
J5: 292303-1
L3: 33u; L2012C
X1, X7: 057-016-10; 057-016-1

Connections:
+3V3: C3.1, C15.1, IC5.3 (VO), J3.1, J3.3, J3.5
+5V: J2.1, J2.2, J2.3, J2.4, J2.P$1, J5.1, X1.11, X1.12, X7.11, X7.12; also elsewhere on the board
+12V: C17.1, J8.1, J8.2, J8.3, J8.4, J8.P$1, L3.1, X1.9, X1.10, X7.9, X7.10; also elsewhere on the board
-12V: J11.1, J11.2, J11.3, J11.4, J11.P$1, X1.1, X1.2, X7.1, X7.2; also elsewhere on the board
GND: C3.2, C15.2, C17.2, C19.2, IC5.2 (GND), J3.2, J3.4, J3.6, J5.4, J5.SH1 (SHIELD), J5.SH2 (SHIELD), J6.1, J6.2, J6.3, J6.4, J6.P$1, J9.1, J9.2, J9.3, J9.4, J9.P$1, J10.1, J10.2, J10.3, J10.4, J10.P$1, X1.3, X1.4, X1.5, X1.6, X1.7, X1.8, X7.3, X7.4, X7.5, X7.6, X7.7, X7.8; also elsewhere on the board
unnamed: C19.1, IC5.1 (VI), L3.2



Board: 4 copper layers, 90.0 x 90.0 mm, 46 parts (24 on the bottom side), 12 nets.

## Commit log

2023-10-24 add stl files
    [connector-cap.stl, tiny-box-18hp.stl, tiny-box-26hp.stl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]
2023-10-24 更新 README.md
2023-10-29 update test report
    [TestReport_SKMW06F-15_and_GSM36B15-P1J.csv, TestReport_SKMW06F-15_and_GSM36B15-P1J.xlsx]
2023-10-29 update power bank support
2023-10-29 update power bank test report
    [TestReport_SKMW06F-15_and_Mi_50w_Power_Bank_20000mAh.csv, TestReport_SKMW06F-15_and_Mi_50w_Power_Bank_20000mAh.xlsx]
2023-10-29 update readme for power bank
2023-11-02 add 3D Print Instructions
2023-11-06 update gcode
    [tiny-rack-2x44hp.v3.support.3mf, tiny-rack.v3.p1s-06-placf-1655g.gcode.3mf]
2023-11-07 add gcode
    [tiny-rack-2x44hp-x1c.3mf, tiny-rack.p1s-06-placf-980g.gcode.3mf, tiny-rack.p1s-06.3mf]
2023-11-07 update 3d print instructions
    [tiny-box-18hp.3mf, tiny-box-18hp.p1s-06-plabasic-135g.gcode.3mf, tiny-box-18hp.p1s-06-placf-131g.gcode.3mf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]
2023-11-07 update 3d print gcode
    [tiny-box-18hp.3mf, tiny-box-18hp.p1s-06-plabasic-135g.gcode.3mf, tiny-box-18hp.p1s-06-placf-131g.gcode.3mf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]
2023-11-10 optimize 3d printing support
    [tiny-rack-2x44hp-x1c.3mf, tiny-rack-2x44hp.v3.stl, tiny-rack-2x44hp.v3.stp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]
2023-11-11 add gcode for petg
    [tiny-rack-2x44hp-x1c-petg.3mf, tiny-rack-2x44hp-x1c.3mf]
2024-09-13 fix mount issue
    [tiny-box-34hp-joke.3mf, tiny-box-34hp-joke.stp]
2025-04-21 v2 init
    [3U52hp-71mm.stp, 3U52hp.3mf, 3U60hp-61mm.stp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]
2025-04-22 update 3d model
    [3U42hp-71mm-2.5hole.stp, 3U42hp.3mf, 3U52hp-71mm-2.5hole.stp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]
2025-05-01 remove untest gcode
    [3U52hp-71mm-2.5hole.translucent.stp, 6U52hp-71mm-2.5hole.translucent.stp, translucent.3mf]
2025-07-19 add gerber file
    [psu_core_BOM.csv, psu_core_PnP.csv, psu_exp_170_BOM.csv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]
2026-02-11 fix 3mf file
    [6U52hp.3mf]
2026-10-20 Added a case suitable for A1 printing. It supports power jack in two different direction and is fully enclosed.

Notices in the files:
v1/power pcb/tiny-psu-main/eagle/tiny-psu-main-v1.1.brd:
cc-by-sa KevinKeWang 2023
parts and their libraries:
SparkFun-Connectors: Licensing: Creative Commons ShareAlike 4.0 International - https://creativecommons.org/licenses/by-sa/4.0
